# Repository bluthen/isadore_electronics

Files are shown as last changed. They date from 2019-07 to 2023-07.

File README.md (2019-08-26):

# isadore_electonics

Design files for the electronics of the Isadore Dryer Management System. Also included is what is called the MID software which queries the electronics and reports it back to the [isadore_server](https://github.com/bluthen/isadore_server/)

# Electronics Manufacture

Electronics manufactures usually want gerbers, centroid file, and a bill of materials. The latest pre-generated versions of these files can usually be found in the out directory (Example: `sensor_unitv3/out/`).

* The centroid and gerbers are in the zip file.
* The bill of materials is in the excel spreadsheet file (xlsx)
* An optional pins.png file may exist to show the manufacturer the location of pin1 for ICs.

Optionally you can generate the gerbers and centroid yourself depending by opening it up in [Eagle](https://www.autodesk.com/products/eagle/overview).

# Electronics Firmware

After you have a sensor unit or sensor hub, you need to program their firmware. To do this you need a AVR ISP programmer. Then there are script to help you program them. `sensor_unitv3/code/make.py`, `sensor_hubv3/code/Makefile`, and `fuse_crystal_clock.sh`.

*Note* you need a 5 pin ISP programmer. Most sold are 10 pin, so an adapter is needed.

To program the units or hubs you need some software installed:

* `avrdude`
* `gcc-avr`
* `avr-libc`

## Sensor Unit
A sensor unit can be programmed in many ways depending on what sensor modules you are going to plug into it.

Here is the help usage for `make.py`

```
Usage: make.py [OPTIONS] ADDRESS
  -h, --help                      Show this screen
  -d, --debug                     Debug build
  -p, --program                   Program unit
  -c, --clean                     Clean
  -f, --fuse                      Set fuse
  --prev303                       Build for prev3.03 unit
  --with-th                       Build with temperature humidty
  --with-pressurev1=m,b           Build in v1 pressure module
  --with-pressurev4a=cal_adjust   Build in v4a pressure module
  --with-pressurev4b=cal_adjust   Build in v4b pressure module
  --with-pressurev5=m,b           Build in v5 pressure module
  --with-anemometer               Build in Anemometer module
  --with-thermo                   Build in thermocouple module
  --with-multit                   Build in Multipoint-temp module
  --with-tach                     Build in tachometer module
```

So for example you might do with a unit, with the programmed placed and the unit powered.
```
python2 make.py -f -c -p --with-pressurev4b=0 102
```

If successful It is now programmed to use the pressurev4 module that gives you pressure/temperature/rh, and responses when address `102` is queried.

## Sensor Hub

To program the hub you would run with the programmer in place and powered:
```
cd sensor_hubv3/code
./fuse_crystal_clock.sh && make program
```

# MID (Master Interface Device)

This is basically the combination of a small computer (raspberry pi) and the hub electronics board. The hub and raspberry pi communicate serially. The hub has voltage regulators to power the raspberry pi.

## HUB<-> pi wiring

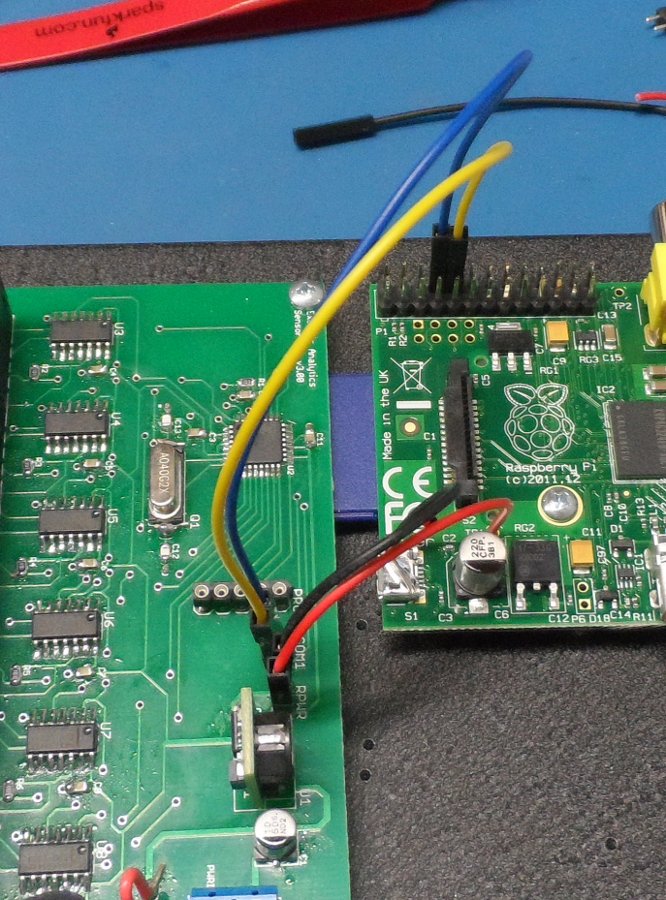
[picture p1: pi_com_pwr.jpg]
HUB Pi wiring diagram


Notice for the power, Red is on TP1, and black is outside of usb connector.

Communication headers on pins 4 and 5 from outside corner.

## Install and configure raspbian

After installing raspian you'll want to set to enable access to the serail port with `raspi-config` and [disable the use of console by uart](https://www.raspberrypi.org/documentation/configuration/uart.md).

```
$ raspi-config
Interface Options->Serial->No->Yes
```

You'll also want to make sure the following are installed:

```
apt-get install python python-pip python-dev
pip install flask pytz requests restkit pyserial pymodbus numpy termcolor netifaces netaddr
```

## Troubleshooting
There is a script called `midsim.py` that can aid in troubleshooting. It allows you to query sensors from the command line. It is located at `sensor_hubv3/code/test/midsim.py` 

Below is the usage:

```
Usage: midsim.py [OPTION]...
  -h, --help            show this screen
  -v, --verbose         output verbose debug output
  -c, --continous=t,c   Keep pulling every t seconds, c many times c=0 for infinite
                        default is to pull once.
  -f, --format=format   The output format to use:
                        default:   The default style output
                        csv:       csv style output
  -t, --type=TYPE       TYPE=(temphum|anemometer|tachometer|thermocouple|pressure|pressurewide|
                              multipointreset|multipointc[1-4]|multipointaddrc[1-4]|ping|
                              unitversion|hubversion) *Required
  --get-cal             Get calibration value for type
  --set-cal=CAL_VALUE   Set calibration value for type
  -p, --port=PORT       PORT=#
  -a, --address=ADDRESS ADDRESS=#,#,#,...
  -u                    use udp instead of serial
  -d, --device=PATH     serial device to use for version 3, default /dev/ttyAMA0
  -o                    Use direct command code instead of general (aka version2)
  -j                    Just send commands then exit immediatly
  -s, --server=IP:PORT  Start midsim server listening on IP:PORT
  -r, --remote=IP:PORT  Query remote midsim server on IP:PORT

  address,port required except for --type=ping
  Max number of addresses is 32.
```

## Calibration
The main goal of the pressure modules was to report differencial pressure. The pressure module can be calibrated and there is a script to help with that process. It takes a large amounts of samples and sets an offset to match the reference. This script can be found at `sensor_hubv3/code/test/calibrator.py`

## Configure mid_software

Copy the mid_software to the raspberry pi. Copy `MID.cfg.example` to `MID.cfg` but one directory down from the location of mid_software. Modify MID.cfg for your needs. The most importanted are `baseurl` and `MIDpassword`Below is a reference for what each key means:

* `baseurl` The url to the base location of your running instance of [isadore_server](https://github.com/bluthen/isadore_server/).
* `MIDname` If you have multiple mids, this needs to be set so it knows which config to fetch. If it doesn't exist, all configs are fetched.
* `MIDpassword` The mid password that was set for your instance of isadore_server.
* `configpath` relative url where it should get the systems unit configuration. shouldn't need changing.
* `uploadpath` the relative url it should use to upload sensor data it gets. shouldn't need changing.
* `rcstatuspath` the relative url it uses for controls. shouldn't need changing.
* `hub_serial` the serial port to use to communicate with the hub electronics board. `/dev/ttyAMA0` on old raspberry pi's, `/dev/serial0` on new ones.
* `STORE_RAW_DATA_MODE` shouldn't need changing
* `RAW_DATA_LOC` shouldn't need changing
* `RS485_TIMEOUT` time out per unit. shouldn't need changing
* `RS485_BAUD` The serial baud rate to use. shouldn't need changing
* `enableRC_p` shouldn't need changing
* `mid_reading_interval_seconds` The minimal amount of time to pass before reading sensor data again.
* `log_level` The level to log at, can be `ERROR`, `WARNING`, or `DEBUG`
* `turn_off` If it should be not be activly getting readings and uploading them.

There are also some other configurations for specific temperature controls. For now for those parameters, please see the code to find them.

## Running mid_software

Put the following in the crontab of the user that is going to run mid_software on the MID. Replace the path to where you copied mid_software.

```
*/15 * * * * /home/pi/mid_software/processCheck.sh
*/10 * * * * /home/pi/mid_software/mid_log_check.sh
```

* `processCheck.sh` will start the process if it doesn't find it running.
* `mid_log_check.sh` tries to detect if the process locked up and will restart it, if it thinks it has.

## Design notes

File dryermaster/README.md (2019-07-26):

# About dryermaster
This code is some example code to read from a dryer master output using SPI ADC Raspberry Pi hat.

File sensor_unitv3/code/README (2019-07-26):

Compile sensor unit with address and feature set

Addresses:
UNITADDR= # < 2^16

UNITFEATURES bit fields 1=enabled 0=disabled
1 bit -- temp-hum
2 bit -- anemometer
3 bit -- tachometer (not enabled, see tachometer code).
4 bit -- bearing/winding thermocouple (not enabled, see tachometer code).
5 bit -- Infineon KP pressure sensor
6 bit -- Freescale MPX pressure sensor

Note: If both KP and MPX are enabled, only KP is used.

UNITFEATURES=1   -- Just temp-hum
UNITFEATURES=2   -- Just anemometer
UNITFEATURES=3   -- both temp-hum and anemometer
UNITFEATURES=17  -- both temp-hum and KP pressure sensor
UNITFEATURES=33  -- both temp-hum and MPX pressure sensor
UNITFEATURE=19   -- temp-hum and KP pressure and annemometer

Ex:
UNITDEFS="-DUNITADDR=102 -DUNITFEATURES=17" make (makeopts)

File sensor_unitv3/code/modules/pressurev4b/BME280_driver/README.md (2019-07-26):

https://github.com/BoschSensortec/BME280_driver.git
CONTENTS OF THIS FILE
=======================
	* Introduction
	* Version
	* Integration details
	* Driver files information
	* Supported sensor interface
	* Copyright

INTRODUCTION
===============
	- This package contains the Bosch Sensortec MEMS humidity sensor driver(sensor API)
	- The sensor driver package includes bme280.h, bme280.c and bme280_support.c files
	
VERSION
=========
	- Version of bme280 sensor driver is:
		* bme280.c - V2.0.4
		* bme280.h - V2.0.4
		* bme280_support.c - V1.0.5

INTEGRATION DETAILS
=====================
	- Integrate bme280.h and bme280.c file in to your project.
	- The bme280_support.c file contains only examples for API use cases, so it is not required to integrate into project.

DRIVER FILES INFORMATION
===========================
	bme280.h
	-----------
		* This header file has the register address definition, constant definitions, data type definition and supported sensor driver calls declarations.

	 bme280.c
	------------
		* This file contains the implementation for the sensor driver APIs.

	 bme280_support.c
	----------------------
		* This file shall be used as an user guidance, here you can find samples of
    			* Initialize the sensor with I2C/SPI communication
        				- Add your code to the SPI and/or I2C bus read and bus write functions.
            					- Return value can be chosen by yourself
           					- API just passes that value to your application code
        				- Add your code to the delay function
        				- Change I2C address accordingly in bme280.h
   			* Power mode configuration of the sensor
   			* Get and set functions usage
			* Reading the sensor read out data

SUPPORTED SENSOR INTERFACE
====================================
	- This humidity sensor driver supports SPI and I2C interfaces

COPYRIGHT
===========
	- Copyright (C) 2013 - 2015 Bosch Sensortec GmbH

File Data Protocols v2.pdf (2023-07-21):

# Data Protocols v2

1 Overview 1.1 Unit Addresses 2 MID ↔ Sensor Hub 2.1 Commands 2.2 Sensor Hub Reply 2.2.1 Readings Reply Data 2.2.1.1 Temp and humidity reply 2.2.1.2 Wind speed reply 2.2.1.3 Tachometer reply 2.2.1.4 K Thermocouple reply 2.2.1.5 Barometric Pressure reply 2.2.1.6 Barometric Pressure Wide reply 2.2.1.7 Differential Pressure Wide reply 2.2.1.8 Multipoint Temp Sensor 2.2.1.8.1 Temperature Reading 2.2.1.8.2 Address Reading 2.2.1.9 Unit Version reply 2.2.1.10 Get Calibration Value reply 2.2.2 Successfully Executed Command (Reply Code 2) 2.2.3 Error Codes 3 Sensor Hub ↔ Sensor Unit 3.1 Changing Address 3.2 Calibration 3.2.1 Get Calibration 3.2.2 Set Calibration

MID ↔ WWW
JSON config download format (MID ← WWW) JSON reading data upload format (MID → WWW) Error codes

# 1 Overview

This document describes the data protocol for communication between EA custom hardware in the Isadore dryer monitoring system.

## 1.1 Unit Addresses

Each sensor unit has a 16 bit address stored in the programming ROM. The unit’s addresses are 16 bit for two reasons:

1. With new RS485 chips it is possible to have 256 or more units on one port. It also makes it easier to have a installation of units of all different addresses and there wouldn’t be a need to make sure they didn’t put one with the same address on the same port.
2. It would make it easier to use replacement units with less of a probability of same address. It is a similar reason why ethernet MAC addresses are 48 bit, no one has 2**48 network cards on a single switch.

# 2 MID ↔ Sensor Hub

The communication between Master Interface Device and Sensor hub will be done through a UDP/IP connection on Port 1082. The Master Interface Device will then send a magic code, command, and optional data (in a single packet), the Sensor Hub will reply to the MID by sending a single UDP packet to the port and address the original command came from. All data is in binary and little endian.

From Master Interface Device:
Magic (4B) | Command (1B) | Data ...
Reply from Sensor Hub:
Reply code(1B) Data...

The magic is 4 bytes:
Magic in hex | 0x44 0x45 0x52 0x56
Magic as little endian 4 byte int | 1448232260
Magic as ASCII | DERV

## 2.1 Commands

The commands the master interface device can send to the sensor hub are listed below. The command is a one byte number and is followed by data depending on the command. Note: the port numbers are one-based, not zero-based.

Command | Code | Data | Version notes
Get temp&hum reading(*) | 1 | Port,N,addr1,addr2,...,addrN ● Port is 1 x uint8 ● N is 1 x uint8 and is a value indicating how many addresses will be given. N needs to be less than or equal to 32 and greater than 0. If there are more than 32 devices connected you need to get the readings by querying again afterwards with another set of <=32 addresses. ● addrX is 1 x uint16 and corresponds to a Sensor Unit connected to the port on the Sensor Hub.
Get wind speed reading | 2 | Same as code 1
Get Tachometer | 3 | Same as code 1
Drive Hz & Current | 4 | Fill This
SP&PV and thermostat | 5 | Fill this
K thermocouple reading | 6 | Same as code 1
Barometric Pressure | 7 | Same as code 1
Barometric Pressure wide | 8 | Same as code 1 | Unit>=3.00
Differential Pressure wide | 14 | Same as code 1 | Unit>=3.01
Multipoint Temp sensor reset | 9 | Same as code 1 | Unit>=3.00
Multipoint Temp sensor reading channel 1 | 10 | Same as code 1 | Unit>=3.00

Multipoint Temp sensor reading channel 2 | 11 | Same as code 1 | Unit>=3.00
Multipoint Temp sensor reading channel 3 | 12 | Same as code 1 | Unit>=3.00
Multipoint Temp sensor reading channel 4 | 13 | Same as code 1 | Unit>=3.00
Multipoint Temp address reading chanel 1 | 14 | Same as code 1 | Unit>= 3.02
Multipoint Temp address reading chanel 2 | 15 | Same as code 1
Multipoint Temp address reading chanel 3 | 16 | Same as code 1
Multipoint Temp address reading chanel 4 | 17 | Same as code 1
General Unit Reading | 25 | Code,R,Port,N,addr1,addr2,...,addrN ● Code is 1 x uint8 from this table ● Port is 1 x uint8 ● R is 1 x uint8 length in bytes of the reply per address (max 8) ● N is 1 x uint8 number of addresses N <= 32 ● addrX is 1 x uint16 sensor unit address Note: Code becomes new command code. | Unit>=v3.00 Hub >=v3.00
Unit version | 63 | Same as code 1 | Unit>=v3.01
Calibration Value | 64 | Code,R,Port,N,addr1,addr2,...,addrN ● Code is 1 x uint8 from this table ● Port is 1 x uint8 ● R is 1 x uint8 length in bytes of the reply per address (max 8) ● N is 1 x uint8 number of | Hub>=3.03

| | addresses N <= 32 ● addrX is 1 x uint16 sensor unit address
Set Calibration Value | 65 | Code,D,Port,A,V ● Code is 1 x uint8 from this table of what calibration value to set. ● D is 1 x uint8 length in bytes of the calibration value V (max 8) ● Port is 1 x uint8 ● A is 1 x uint16 sensor unit address ● V is 1 x D bytes | Hub>=3.03
Ping | 130 | 1 x uint16
Hub version | 150 | 1 x uint16 | Hub>=3.03
Reserved | 200 | Reserved for unit change address (Section 3.1)

* - Time between measurements should be greater than 1s on per sensor basis to reduce the temperature sensor from heating up and reporting the heat of the chip instead of the air.
** - may not be implemented in prototype

## 2.2 Sensor Hub Reply

The sensor hub will give a reply after a command has been given. The reply may be any number of the following depending on the command. For example, a port reading command may have a reply of several error codes (Code 4) before a reading reply (Code 1). When the sensor is done replying it will disconnect the TCP/IP connection.

Reading time
The maximum time it takes for a unit to get temperature and humidity is 824ms although almost always it will be much faster. The base Hub will wait a maximum of N*4s. While the hub board is waiting it won't be able to process any other commands so the timeout should be greater than 128 seconds (32*4s) for the MID if the timeout needs to be set to a static value, or N*4s if it can be set dynamically. N is the number of units addressed.
Reply | Code | Data
Readings Reply | 1 | S,CC,DATA ● S 1xuint8, size in bytes of DATA ● CC 1 x uint8, original command code given

| | ● DATA is S bytes, see Readings Reply section below.
Success executed command | 2 | N,echo ● N is 1 x uint8 ● echo is data given in command. N is number of bytes in echo
Pong, response to Ping | 3 | P ● P is 1x uint16 and is the number given by Ping incremented by 1.
Error | 4 | L,C_1,A_2,..,C_L,A_L ● L is 1 x uint8 ● C_X is 1 x uint8 ● A_X is 1 x uint8 L<=N See Error Codes section for more details.
Hub version reply | 5 | V ● V is 1xuint16

### 2.2.1 Readings Reply Data

Type | CC | DATA
Temp and humidity reply | 1 | N,T1,H1,T2,H2,...,TN,HN ● N is 1 x uint8 ● TX is 1xuint16 ● HX is 1 x uint16 N should match N in initial command. See Temp and humidity reply section for more details.
Wind speed reply | 2 | N,V1,V2,...VN ● VX is 1 x uint16 See wind speed reply section for more details.

Tachometer reply | 3 | N,R1,R2,...,RN ● RX is 1 x uint16 See Tachometer reply section for more details.
Drive Hz & Current reply | 4 | V,I Fill out
SP&PV and Thermostat set value reply | 5 | Fill out
K thermocouple reply | 6 | N,W1,B1,W2,B2,...,WN,BN ● N is 1 x uint8 ● WX is 1 x uint16 TC 1 temp ● BX is 1 x uint16 TC 2 temp See K Thermocouple reply section for more details.
Barometric Pressure reply | 7 | N,P1,P2,...,PN ● N is 1 x uint8 ● PX is 1 x uint16 See Barometric Pressure reply section for more details.
Barometric Pressure wide reply | 8 | N,P1,P2,...,PN ● N is 1 x uint8 ● PX is 1 x uint32 See Barometric Pressure wide reply section for more details.
Differential Pressure wide reply | 14 | N,P1,P2,...,PN ● N is 1 x uint8 ● PX is 1 x uint32 See Differential Pressure wide reply section for more details.
Multipoint Temp Sensor reset reply | 9 | N,P1,P2,...,PN ● N is 1 x uint8 ● PX is 1 x uint8 See Multipoint Temp Sensor section below.
Multipoint Temp sensor reading address channel 1-4 reply | 14-17 | N,A1,A2,...,AN ● N is 1 x uint8 ● AX is 1 x uint64 See Multipoint Temp Sensor section below.
Multipoint Temp sensor reading temperature channel 1-4 reply | 10-13 | N,P1,P2,...,PN ● N is 1 x uint8 ● PX is 1 x uint16

| | See Multipoint Temp Sensor section below.
Unit version | 63 | N,V1,V2,...,VN ● VX is 1 x uint16 See Unit Version reply section for more details
Calibration value | 64 | N,V1,V2,...,VN ● VX is 1 x R See Calibration value reply section for more details
Reserved | 200 | Reserved (Section 3.1)

### 2.2.1.1 Temp and humidity reply

The temperature and humidity readings that are sent back are raw values replied back in the same order given in the command. Some calculations will have to be done.

Temperature Calculation
Note: This conversion works for both SHT-75 and PressureV4.1 sensors.
Temperature data is given to the MIB as uint16 (T), to convert this number into Fahrenheit :

1

F = d

1 + d
2

T

d

1 =− 40. 2

d

2 = 0. 018

Humidity Calculation
There are two sensor that give humidity the SHT-75 and PressureV4.1 module. An attempt was made to make the pressure module compatible was it proved difficult to keep the firmware size under 8k.

Humidity data is given to the MIB as uint16 (H),

PressureV4.1
RH

true = H/100. 0
Example H might be 3418
RH

true = 3418/100. 0 = 34. 19%

1See section 4.3 in SHT7X datasheet, sensor running at 5V.

SHT-75
The following conversions when SHT-75 is in use is listed below .

2

RHlinear = c

1 + c
2

H + c
3

H

2

c

1 =− 2. 0468

c

2 = 0. 0367

c

3 =− 1. 5955 · 10

−6

RH is relative humidity if temperature is 77F, to compensate for temperature you can use
linear
the formula below.

RH

true = T
| c

( − 25) t
1 + t
2
( | H) + RHlinear

t

1 = 0. 01

t

2 = 0. 00008

T

c = T
f

( − 32)/1. 8

T is temperature in Fahrenheit.
f

Unit unresponsive

If both temperature and humidity uint16 values are zero (0x0000) for a unit then that will indicate there was a problem getting the data for that addresses. An error reply code would also be given for that address.

Reference documents
- Introduction to Relative Humidity http://www.sensirion.com/en/pdf/product_information/Introduction_to_Relative_Humidity_E.pdf (http://www.sensirion.com/en/pdf/product_information/Introduction_to_Relative_Humidity_E.pdf)
- Humidity Formulae
http://www.sensirion.com/en/pdf/product_information/AN-humidity-formulae.pdf
- SHT7X datasheet
http://www.sensirion.com/en/pdf/product_information/Datasheet-humidity-sensor-SHT7x. pdf (http://www.sensirion.com/en/pdf/product_information/Datasheet-humidity-sensor-SHT7x.pdf)

### 2.2.1.2 Wind speed reply

V is the value from the unit, a rolling average of up to 30 30s time periods

2See section 4.1 and 4.2 in SHT7X datasheet.

To find V in mph:
V

mpℎ = V/100. 0

### 2.2.1.3 Tachometer reply

The replied value R is the last value of rpm calculated by the sensor. The following formula may be useful.

Calculate frequency (Hertz)
f = R/60

### 2.2.1.4 K Thermocouple reply

The following formula should be used to get the temperature in Celsius.

D is the integer value read.

T

c = 1023. 75

D
2

12

### 2.2.1.5 Barometric Pressure reply

The following formula should be used to get the absolute pressure in kilo pascals. D is the integer uint16 read.

P = 0. 0022888 · D + 50

It doesn’t matter which sensor is in the unit the MPX or KP the conversion to a common function is done in the unit.

### 2.2.1.6 Barometric Pressure Wide reply

The following formula should be used to get the absolute pressure in kilo pascals. D is the integer uint32 read. D comes in units of in Pascals.

P = D/1000. 0

Calibration info

- R - 4 (int32)
- V - value in pascals, positive or negative TODO: Not implemented

### 2.2.1.7 Differential Pressure Wide reply

The following formula should be used to get the differential pressure in kilopascals.
D is the integer uint32 read. D comes in units of centipascals. Note: This can report a negative pressure differential.

P = (D − 2147483647)/100000

Calibration info

- R - 4 (int32)
- V - value in centipascals, positive or negative TODO: Not implemented

### 2.2.1.8 Multipoint Temp Sensor

The multipoint temperature sensor module can takes cables with many temperature sensors on them.

### 2.2.1.8.1 Temperature Reading

Reading temperature values should go like the following:
1. X is the channel we want to read (1,2,3,4)
2. Multipoint Temp Reset (code 9) sent to units
3. Multipoint Temp reading (code [9+X]) sent to units
4. Repeat step 3. until all units report back 0xFFFF
5. If desire to read from another channel change start at step 1.
It is incorrect to change channels without a reset, it will give unexpected results.

On a multipoint temperature cable there are a number of ds18b20 sensors. When the unit gets the code to read the temperature it probes for a ds18b20 address, then reads the temperature from that address. When the unit gets the code again it will probe for the next ds18b20 address and read the temperature. At the point when there are no more ds18b20 temperature sensors on the cable it will reply back the value 0xFFFF. It will continue to reply 0xFFFF until a reset command is issued.

The order in which a value is read from a particular sensor is dependent on the sensor’s address and not the position the sensor is on the cable. The order will be the same for a particular cable. Thus sensors can be identified by query index, and one can manually map a location and query index.

The multipoint temperature sensor module supports up to four channels (Up to four multipoint sensor cables). You should never take readings from a different channel without sending a reset

first.

The number of sensors on a cable is not fixed, so you can have some units or channels with more or less sensors than others. This is why you should do readings until all sensors reply back 0xFFFF, while ignoring the units that reply with a 0xFFFF reading (This means you have reached the end of the sensors on that particular channel for that unit).

The following algorithm should be used to get the temperature in Celsius.
‘ds18b20_value’ sent to the function is the integer uint16 read.

double ds18b20_conversion(uint16_t ds18b20_value)
{
uint8_t digits;
uint8_t decimals;
uint16_t t = ds18b20_value; double negative = 1.0;
if (t & 0xF800) {
negative = -1.0;
t=~t+1;
}
digits = (uint8_t)((t&0x07F0) >> 4);
decimals = t & 0x000F;
return negative*((double)digits + (double)decimals/16.0);
}

If you want to test your conversion function, you can test with these values listed:

Value(Hex) | Temperature (C)
0x07D0 | 125
0x0550 | 85
0x0191 | 25.0625
0x00A2 | 10.125
0x0008 | 0.5
0x0000 | 0
0xFFF8 | -0.5
0xFF5E | -10.125

0xFE6F | -25.0625
0xFC90 | -55

### 2.2.1.8.2 Address Reading

Readings addresses is done in a similar fashion to reading the temperature. The size of the data returned is different(8 bytes instead of 2 bytes) and the command code is different.

Reading address values should go like the following:
1. X is the channel we want to read (1,2,3,4)
2. Multipoint Temp Reset (code 9) sent to units
3. Multipoint Temp reading (code [13+X]) sent to units
4. Repeat step 3. until all units report back 0xFFFFFFFF
5. If desire to read from another channel change start at step 1.
It is incorrect to change channels without a reset, it will give unexpected results.

### 2.2.1.9 Unit Version reply

V is integer uint16 read. V value to version

V Version

1 | 3.00 + V/100

Unit version before 3.01 do not support the version command code.

### 2.2.1.10 Get Calibration Value reply

See each code to see what the reply value means. Will get an error response back in calibration is currently not supported for a command code in the unit version.

### 2.2.2 Successfully Executed Command (Reply Code 2)

This reply command is only a valid reply for non-reading, and non-ping commands. For example this is a valid reply for command codes 5 and 6. You will not get this reply for command codes 1, 2, 3, 4, 7.

### 2.2.3 Error Codes

The error reply code data consists is composed of the following:

L(1B) | C_1(1B) | A_1(1B) | ... | C_L(1B) | A_L(1B)

The number of bytes in the data part of a error reply is 2*L+1. C_X is a code indicating the error listed in the below table. A_X is the index of the address of the sensor unit that had the error. If A_1=1 then the sensor unit from the first address given in command has the error C_1 associated with it. If A_X=0 this means it is a general error that doesn’t belong to any sensor unit.

Note: More error codes will probably get added later.

Code | Error | Includes Address | Recommended Action
1 | Ethernet board responsive but rest of sensor hub timed out. | No | Try request again.
2 | Invalid number of addresses to query on port reading. | No | Try request again.
3 | Reply size to large. This probably shouldn’t happen, it would indicate a bug somewhere in the microcontroller code. | No | Try request again.
4 | Sensor unit timed out or unit not on port. Address is the sensor unit that timed out. | Yes | Throw measurement away.
5 | Unsupported command code | No
6 | Sensor unit’s reply failed CRC8 check. | Yes | Throw measurement away.
7 | Unit reply size mismatch (wacked out unit, or wrong firmware or something). | Yes | Throw measurement away.
8 | Bad magic from MID. | No | Try request again.
9 | Hub timed out. (MID generated) | No | Try request again.
10 | Unit is not configured with sensor (Ex. Asked for wind speed when not configured with | Yes | Throw measurement away.

anemometer).

# 3 Sensor Hub ↔ Sensor Unit

The sensor hub will send a request addressed to a particular sensor unit on the correct port. The sensor unit and only that sensor unit will then respond through the RS485 network. Communication between sensor hub and sensor unit is binary little endian.

Request:
Magic (4B) | | Address (2B) | CC (1B)
Reply:
Magic (4B) | Address (2B) | CC(1B
| | )
S (1B) | Data
| | | (SB) CRC8 (1B)

## 3.1 Changing Address

This only works for v3 sensor units

Request:
Magic(4B) | 00 (2B) | 200 (1B) | New Address (2B)
Reply:
None

## 3.2 Calibration

### 3.2.1 Get Calibration

Request:
Magic (4B) | Address (2B) | 64(1B) | CC (1B)
Reply:
Magic (4B) | Address (2B) | 64(1B) | S (1B) | Data | CRC8

(SB) (1B)

### 3.2.2 Set Calibration

Request:
Magic (4B) | Address (2B) | 65(1B) | CC (1B) | V(DB)
Reply:
Magic (4B) | Address (2B) | 65(1B) | S (1B) | V (SB) | CRC8 (1B)

# MID ↔ WWW

## JSON config download format (MID ← WWW)

queryInterval:

midPass:

enabled_p:

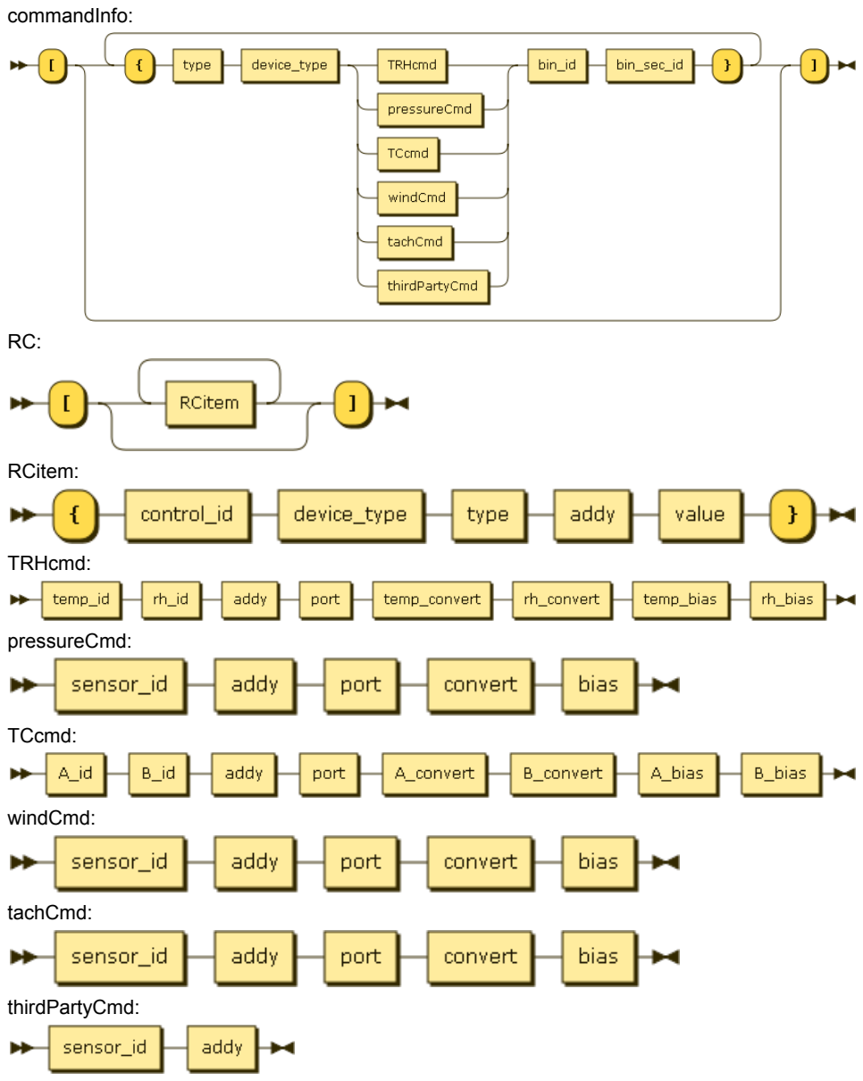
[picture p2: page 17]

commandInfo:

RC:

RCitem:

TRHcmd:

pressureCmd:

TCcmd:

windCmd:

tachCmd:

thirdPartyCmd:

Addy:

## JSON reading data upload format (MID → WWW)³

MIDtoWWW

passwd

datetime

data

errors

datum

### Error codes

Code | Description | Recommended action
1-10 | See table of MID/hub error codes
51 | Error encountered while parsing hub response | Throw measurement away

3Created using http://bottlecaps.de/rr/ui. EBNF syntax saved in MID repository.

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
hile
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
e, t

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
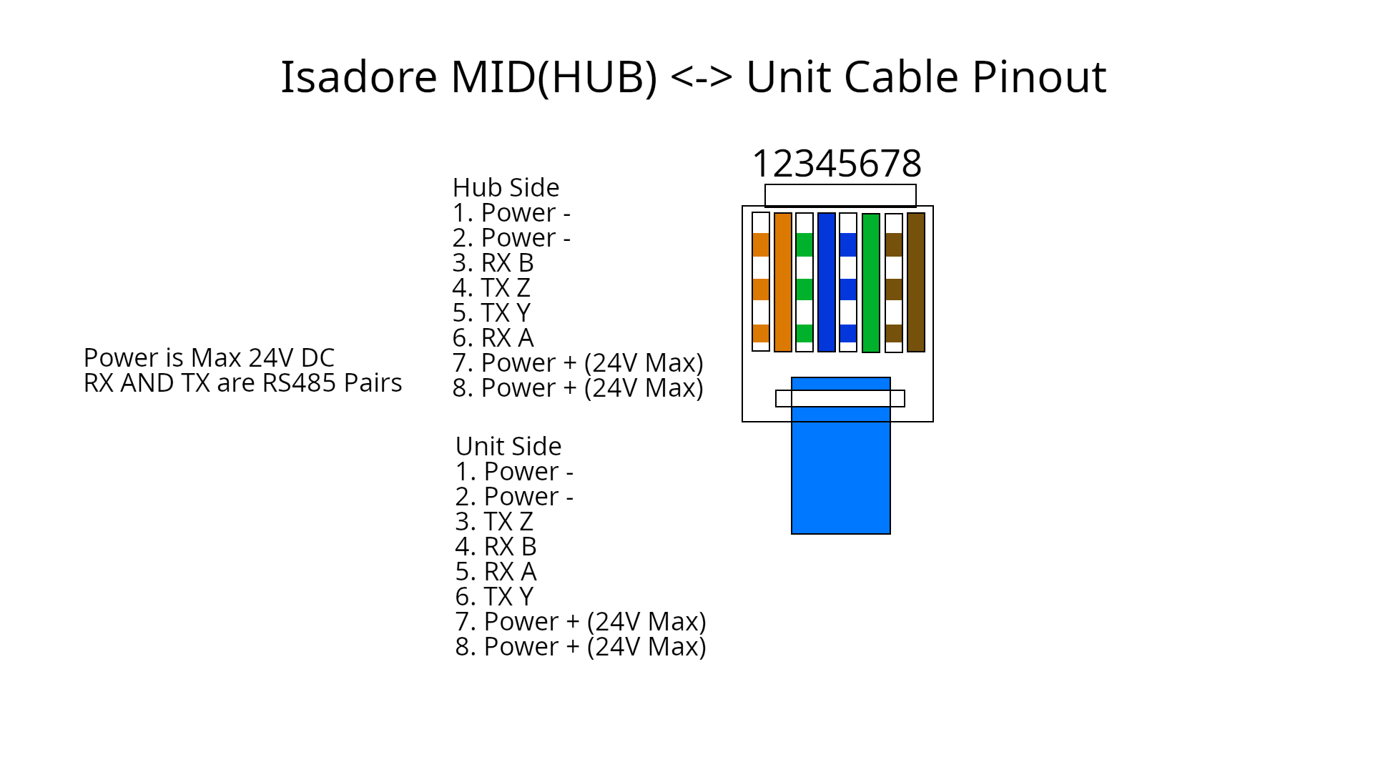
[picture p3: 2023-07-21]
HUB_UNIT_Pinout.png

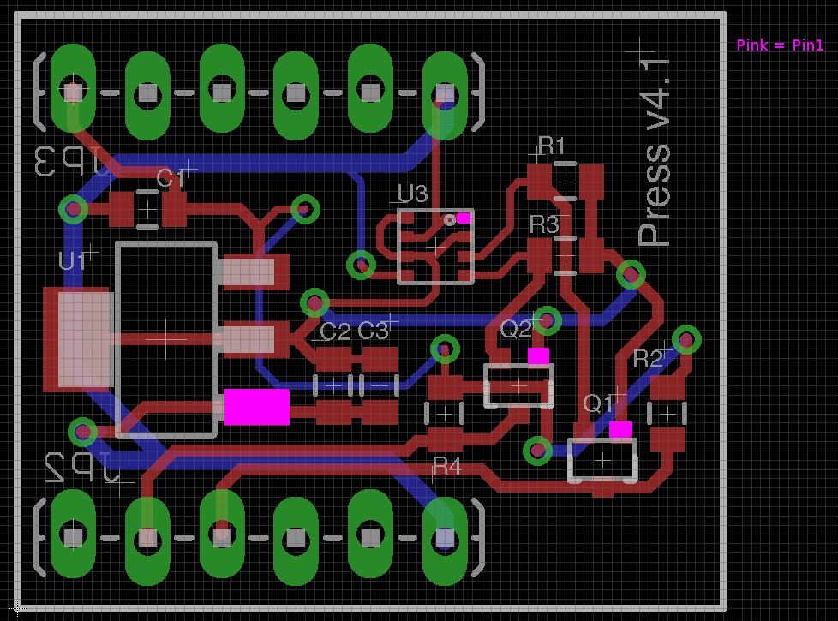
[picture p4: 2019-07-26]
sensor_unit_modules/pressureMv4/out/pressureMv4.10-pin1.png

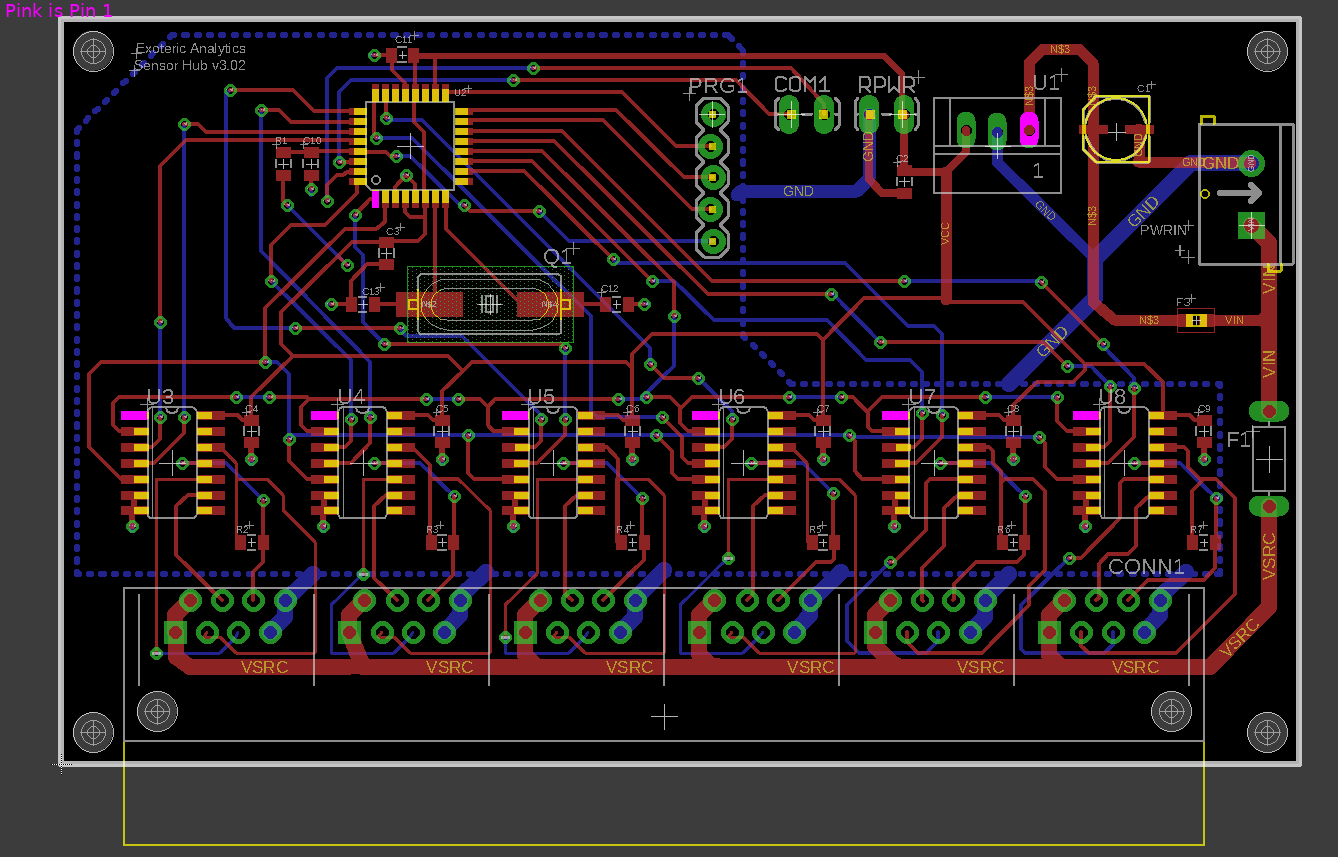
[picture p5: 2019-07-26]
sensor_hubv3/out/sensor_hubv3.02pins.png

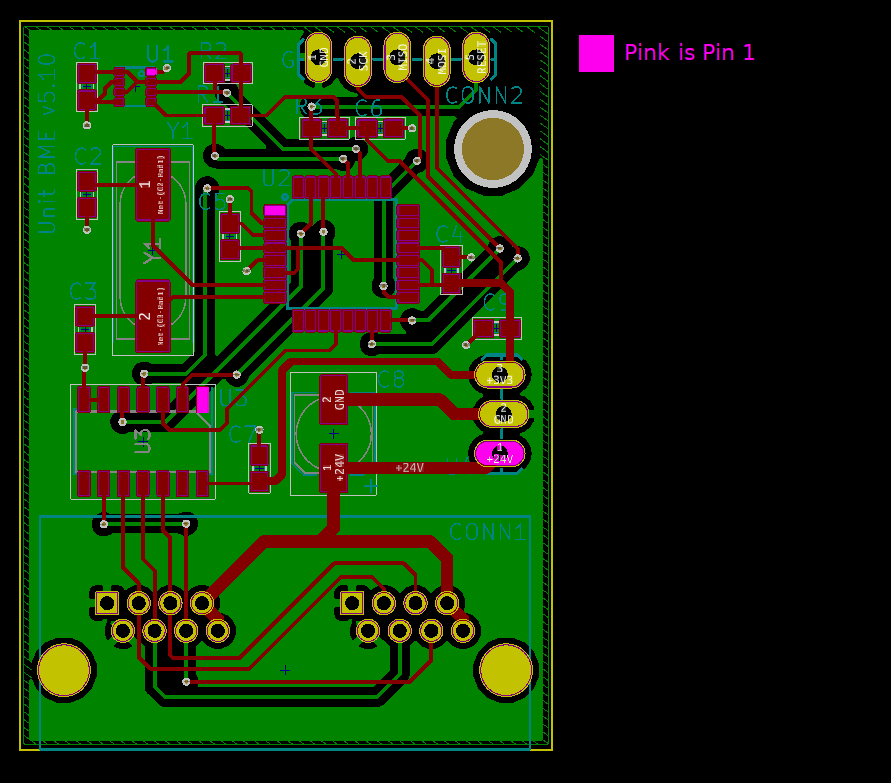
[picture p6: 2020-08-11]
sensor_unit_bme280/gerbers/sensor_unit_bme280v5.10_pin1.png

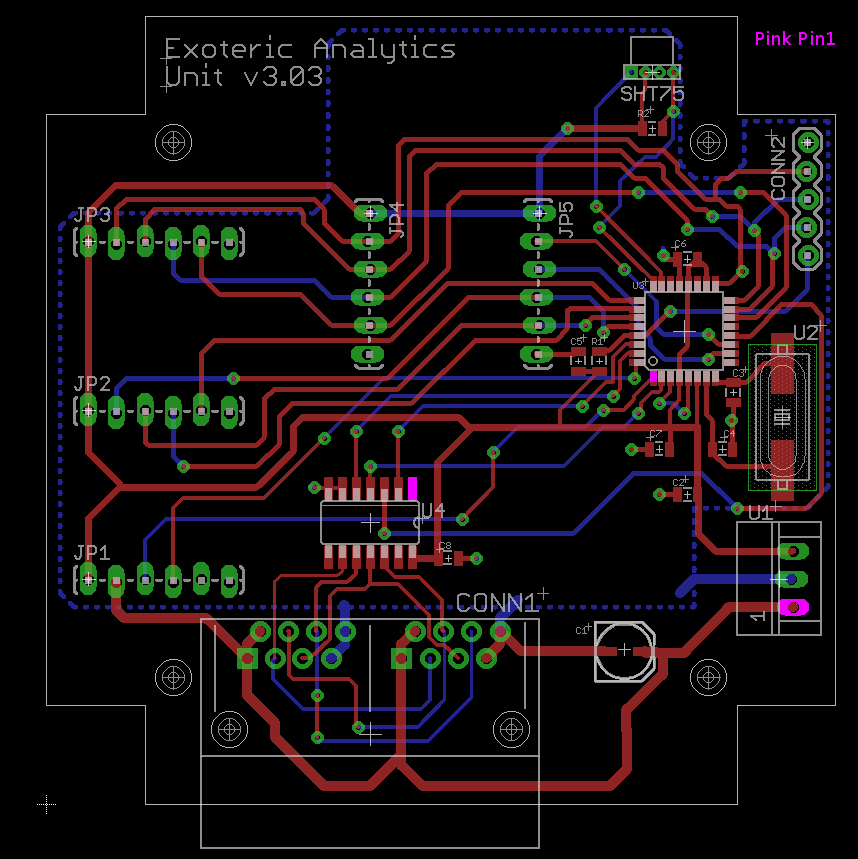
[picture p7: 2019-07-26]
sensor_unitv3/out/sensor_unitv3.03pins.png

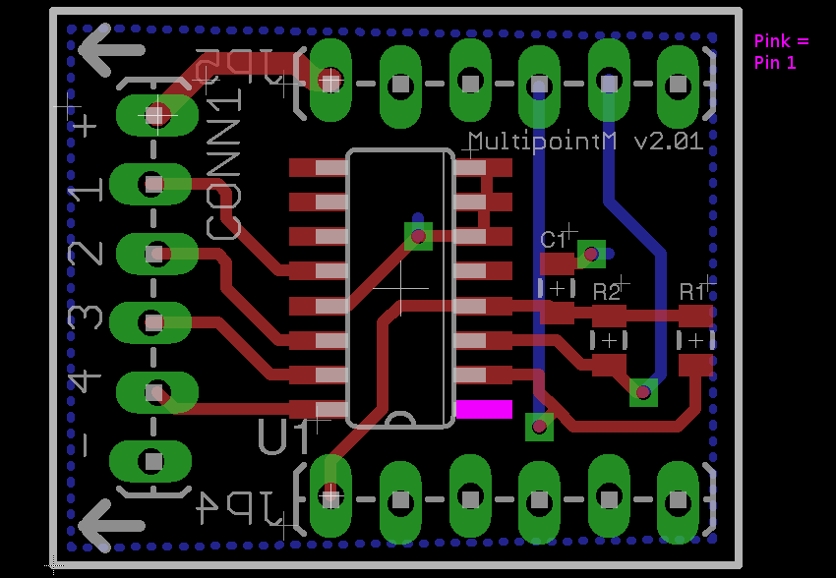
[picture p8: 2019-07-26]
sensor_unit_modules/multipointMv2/out/multipointMv2.01-pin1.png

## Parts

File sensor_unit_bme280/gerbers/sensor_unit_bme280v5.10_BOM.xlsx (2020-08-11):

Labels | Part | Primary Source | Notes
C1, C4, C5, C6, C7 | 0603 0.1uF/50V X7R | Digikey: 445-5666-1-ND (https://www.digikey.com/product-detail/en/tdk-corporation/CGA3E2X7R1H104K080AA/445-5666-1-ND/2443706)
C2, C3 | 0603 22pF 10V cap | Digikey: 399-7874-1-ND (https://www.digikey.com/product-detail/en/kemet/C0603C220J1GACTU/399-7874-1-ND/3471597)
C8 | Panasonic C 10UF 50V | Digikey: PCE4608CT-ND (https://www.digikey.com/product-detail/en/panasonic-electronic-components/EEE-1HA100WAR/PCE4608CT-ND/1718031)
C9 | 0603 10uF/10V | Digikey: 490-14372-1-ND (https://www.digikey.com/product-detail/en/murata-electronics/GRM188R61A106KE69J/490-14372-1-ND/6606833)
CONN1 | connector - 2 port Female RJ45 (8P8C) | Digikey: E5J88-00AJG2-L (https://www.digikey.com/product-detail/en/pulse-electronics-network/E5J88-00AJG2-L/1840-1049-ND/1785309)
CONN2 | Leave unpopulated | Leave unpopulated
R1, R2 | 0603 4.7k ohm resistor | Digikey: 311-4.7KGRCT-ND (https://www.digikey.com/product-detail/en/yageo/RC0603JR-074K7L/311-4.7KGRCT-ND/729732)
R3 | 0603 10k ohm resistor | Digikey: P10KGCT-ND (https://www.digikey.com/product-detail/en/panasonic-electronic-components/ERJ-3GEYJ103V/P10KGCT-ND/134717)
U1 | BME280 Sensor | Digikey: 828-1063-1-ND (https://www.digikey.com/product-detail/en/bosch-sensortec/BME280/828-1063-1-ND/6136314)
U2 | TQFP ATMega328 | Digikey: ATMEGA328P-AURCT-ND (http://www.digikey.com/product-detail/en/atmel/ATMEGA328P-AUR/ATMEGA328P-AURCT-ND/3789455)
U3 | 14-SOIC RS485 fullduplex transceiver 3.3V | Digikey: ISL83070EIBZA-TCT-ND (https://www.digikey.com/product-detail/en/renesas-electronics-america-inc/ISL83070EIBZA-T/ISL83070EIBZA-TCT-ND/1034268)
U4 | DC-DC 3.3V Switching regulator | Digikey: VXO7803-500 (https://www.digikey.com/product-detail/en/cui-inc/VXO7803-500/102-4248-ND/7350287)
Y1 | HC49 4 Mhz Crystal | Digikey: 535-10202-1-ND (http://www.digikey.com/product-detail/en/ABLS-4.000MHZ-B4-T/535-10202-1-ND/2184237)

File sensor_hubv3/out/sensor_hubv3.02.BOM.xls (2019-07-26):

Labels | Part | Digikey (Digikey #) | Newark (Newark #)
U1 | Power module OKI-78SR | 0
U2 | TQFP ATMega328 | 0
U3, U4, U5, U6, U7, U8 | SOIC-14 MAX13448 +/-80V Fault protection RS485 full duplex transceiver | 0
Q1 | HC49 4 Mhz Crystal | 0
C2 | 0805 10uF/10V | 0
C1 | Panasonic C 10UF 50V | 0
C3, C4, C5, C6, C7, C8, C9, C10, C11 | 0805 0.1 uF 10V cap | 0
C12, C13 | 0805 22pF 10V cap | 0
R1 | 0805 10k resistor | 0
R2, R3, R4, R5, R6, R7 | 0805 100 Ohm resistor | 0
PRG1 | female swiss header .1" 5 position straight | 0
CONN1 | 6 port Female RJ45 Connector | 0
COM1, RPWR | 0.1" male headers | 0
F1 | 25 Ohm 2A NTC |  | 0
F3 | 0603 0 ohm resistor (jumper) | 541-0.0GTR-ND
PWRIN | Screw Terminals 5mm Pitch (2-Pin) | 0

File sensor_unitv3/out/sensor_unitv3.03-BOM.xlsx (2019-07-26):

Labels | Part | Primary Source
C1 | Panasonic C 10UF 50V | Digikey: PCE4608CT-ND (https://www.digikey.com/product-detail/en/panasonic-electronic-components/EEE-1HA100WAR/PCE4608CT-ND/1718031)
C2 | 0805 10uF/10V | Digikey: 399-8015-2-ND (http://www.digikey.com/product-detail/en/kemet/C0805C106Z8VACTU/399-8015-2-ND/2211789)
C3, C4 | 0805 22pF 10V cap | Digikey: 399-1113-1-ND (http://www.digikey.com/product-detail/en/C0805C220J5GACTU/399-1113-1-ND/411388)
C5, C6, C7, C8 | 0805 0.1 uF 10V cap | Digikey: 478-3755-1-ND (http://www.digikey.com/product-detail/en/08053C104KAT2A/478-3755-1-ND/1116453)
CONN1 | connector - 2 port Female RJ45 (8P8C) | Digikey: A31449-ND (https://www.digikey.com/product-detail/en/te-connectivity-amp-connectors/5557560-1/A31449-ND/769593)
CONN2 | female swiss header .1" 5 position straight | Digikey: SAM1119-32-ND (http://www.digikey.com/product-detail/en/SS-132-TT-2/SAM1119-32-ND/1105687)
JP1, JP2, JP3, JP4, JP5 | female header .1" 6 position straight | Digikey: S7004-ND (http://www.digikey.com/product-detail/en/PPTC061LFBN-RC/S7004-ND/810145)
R1, R2 | 0805 10k resistor | Digikey: 311-10KARCT-ND (http://www.digikey.com/product-detail/en/RC0805JR-0710KL/311-10KARCT-ND/731188)
SHT75 | header .050" GRID 4 POS straight | Digikey: S9008E-04-ND (http://www.digikey.com/product-detail/en/LPPB041NFFN-RC/S9008E-04-ND/1786362)
U1 | Power module OKI-78SR | Digikey: 811-2196-5-ND (http://www.digikey.com/product-detail/en/OKI-78SR-5%2F1.5-W36-C/811-2196-5-ND/2259781)
U2 | HC49 4 Mhz Crystal | Digikey: 535-10202-1-ND (http://www.digikey.com/product-detail/en/ABLS-4.000MHZ-B4-T/535-10202-1-ND/2184237)
U3 | TQFP ATMega328 | Digikey: ATMEGA328P-AURCT-ND (http://www.digikey.com/product-detail/en/atmel/ATMEGA328P-AUR/ATMEGA328P-AURCT-ND/3789455)
U4 | SOIC-14 MAX13448 +/-80V Fault protection RS485 full duplex transceiver | Digikey: MAX13448EESD+-ND (http://www.digikey.com/product-detail/en/MAX13448EESD%2B/MAX13448EESD%2B-ND/1937474)

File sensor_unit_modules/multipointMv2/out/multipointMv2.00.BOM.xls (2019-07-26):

Labels | Part | Digikey (Digikey #) | Mouser (Mouser Part #)
U1 | SO16 DS2482S-800 1-wire bridge | DS2482S-800+-ND | 700-DS2482S-800
R1, R2 | 0805 4.7k Ohm resistor | 311-4.7KARCT-ND
C1 | 0805 0.1uF capacitor 10V | 478-3755-1-ND
JP4, JP5 | header 14.5mm 6 way long leds (arduino like) |  | 782-A000084
CONN1 | 0.1" 6 pos screw terminal block | A98337-ND

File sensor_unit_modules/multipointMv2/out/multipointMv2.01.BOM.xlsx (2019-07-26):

Labels | Part | Primary Source | Secondary Source | Notes
U1 | SO16 DS2482S-800 1-wire bridge | Digikey: DS2482S-800+-ND (http://www.digikey.com/product-detail/en/DS2482S-800%2B/DS2482S-800%2B-ND/1197437) | Mouser: 700-DS2482S-800 (http://www.mouser.com/ProductDetail/Maxim-Integrated/DS2482S-800+/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)
R1, R2 | 0805 4.7k Ohm resistor | Digikey: 311-4.7KARCT-ND (http://www.digikey.com/product-detail/en/RC0805JR-074K7L/311-4.7KARCT-ND/731274)
C1 | 0805 0.1uF capacitor 10V | Digikey: 478-3755-1-ND (http://www.digikey.com/product-detail/en/08053C104KAT2A/478-3755-1-ND/1116453)
JP4, JP5 | 0.1" male headers 6conn | Digikey: A26514-40-ND (http://www.digikey.com/product-detail/en/4-103327-0/A26514-40-ND/297924) |  | Mounted on the back
CONN1 | 0.1" 6 pos screw terminal block | Digikey: A98337-ND (http://www.digikey.com/product-detail/en/282834-6/A98337-ND/1153267)

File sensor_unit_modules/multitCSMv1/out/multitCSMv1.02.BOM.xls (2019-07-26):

Labels | Part | Primary Source | Secondary Source | Assembly Notes
U1 | 8-SOIC DS18B20 | DS18B20Z+-ND (http://www.digikey.com/product-detail/en/DS18B20Z%2B/DS18B20Z%2B-ND/956982) | 700-DS18B20Z (http://www.mouser.com/ProductDetail/Maxim-Integrated/DS18B20Z+/?qs=sGAEpiMZZMvbyeSUH4qH%2fLnY%252bzqr5uOI)
P1, P2 | 3 conn screw terminal, 0.150" (3.81mm) pitch | Digikey: 609-3919-ND (https://www.digikey.com/product-search/en?keywords=609-3919-ND) |  | Connection slots facing outward

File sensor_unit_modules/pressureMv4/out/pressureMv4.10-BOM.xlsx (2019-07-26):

Labels | Part | Primary Source | Secondary Source | Notes
U1 | SOT-223 LM1117 compatible LDO 3.3V Voltage Regulator | Digikey: NCP1117LPST33T3GOSCT-ND (http://www.digikey.com/product-detail/en/NCP1117LPST33T3G/NCP1117LPST33T3GOSCT-ND/3462387)
U2 | BME280 | Digikey: 828-1063-1-ND (https://www.digikey.com/product-detail/en/bosch-sensortec/BME280/828-1063-1-ND/6136314) | Future Electronics: BME280BOSCH2053946 (http://www.futureelectronics.com/en/Technologies/Product.aspx?ProductID=BME280BOSCH2053946&IM=0)
C1, C2 | 0805 10uF/10V X7R | Digikey: 399-8015-2-ND (http://www.digikey.com/product-detail/en/kemet/C0805C106Z8VACTU/399-8015-2-ND/2211789)
R1, R2, R3, R4 | 0805 10k Ohm resistor | Digikey: 311-10KARCT-ND (http://www.digikey.com/product-detail/en/RC0805JR-0710KL/311-10KARCT-ND/731188)
C3 | 0805 0.1uF capacitor 10V X7R | Digikey: 478-3755-1-ND (http://www.digikey.com/product-detail/en/08053C104KAT2A/478-3755-1-ND/1116453)
Q1, Q2 | BSS138 FET SOT-323 | Digikey: BSS138WCT-ND (http://www.digikey.com/product-detail/en/BSS138W/BSS138WCT-ND/3907886)
JP2, JP3 | 0.1" male headers 6conn | A26514-40-ND (http://www.digikey.com/product-detail/en/4-103327-0/A26514-40-ND/297924) |  | Mounted on the back

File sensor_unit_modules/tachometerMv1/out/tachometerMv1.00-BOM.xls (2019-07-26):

Labels | Part | Digikey (Digikey #) | Mouser (Mouser Part #)
42EF | terminal block - 3 pin, 0.1" spacing | A98334-ND
JP1, JP2 | header 14.5mm 6 way long leds (arduino like) |  | 782-A000084

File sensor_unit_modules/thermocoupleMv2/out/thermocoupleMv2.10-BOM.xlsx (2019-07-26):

Labels | Part | Primary Source | Secondary Source | Assembly/Substitute part Notes
TC | terminal block - 2 pin, 0.1" spacing | Digikey: A98334-ND (http://search.digikey.com/scripts/DkSearch/dksus.dll?lang=en&site=US&KeyWords=A98334-ND&x=32&y=19)
JP2, JP3 | 0.1" male headers 6conn | Digikey: A26514-40-ND (http://www.digikey.com/product-detail/en/4-103327-0/A26514-40-ND/297924) |  | Mounted on the back
U1 | SOT-223 LM1117 compatible LDO 3.3V Voltage Regulator | Digikey: NCP1117LPST33T3GOSCT-ND (http://www.digikey.com/product-detail/en/NCP1117LPST33T3G/NCP1117LPST33T3GOSCT-ND/3462387)
C1, C2, C3 | 0805 10uF/10V | Digikey: 445-1371-1-ND (http://www.digikey.com/product-detail/en/C2012Y5V1A106Z/445-1371-1-ND/567608)
C4 | 0805 0.1uF capacitor 10V | Digikey: 478-3755-1-ND (http://www.digikey.com/product-detail/en/08053C104KAT2A/478-3755-1-ND/1116453)
R1, R2, R3, R4 | 0805 10k resistor | Digikey: 311-10KARCT-ND (http://www.digikey.com/product-detail/en/RC0805JR-0710KL/311-10KARCT-ND/731188)
U2 | MAX31855KASA+ Type K | Digikey: MAX31855KASA+TCT-ND (http://www.digikey.com/product-detail/en/MAX31855KASA%2BT/MAX31855KASA%2BTCT-ND/2708805)

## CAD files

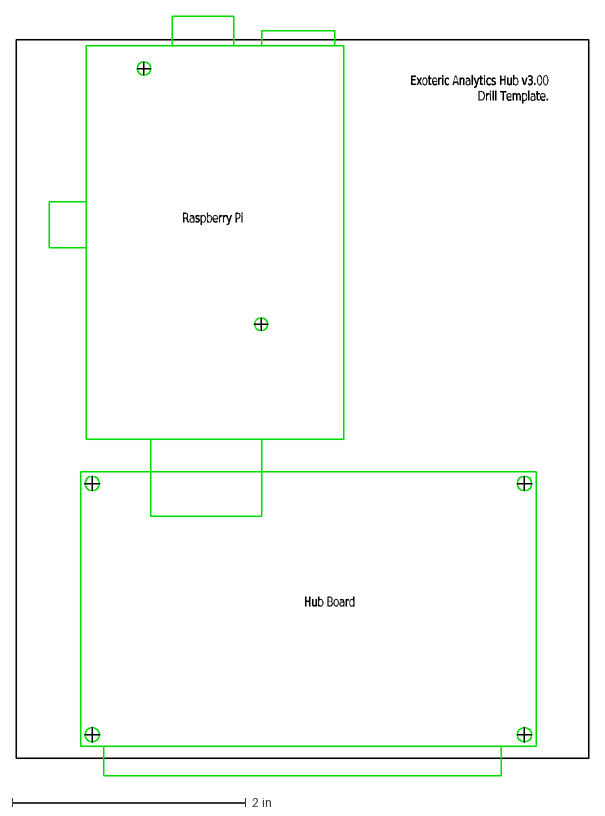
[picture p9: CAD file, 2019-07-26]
enclosures/hubv3/hub_drill_template_v3.00.dxf
Exoteric\~Analytics\~Hub\~v3.00\~ Drill\~Template.
Raspberry\~Pi
Hub\~Board

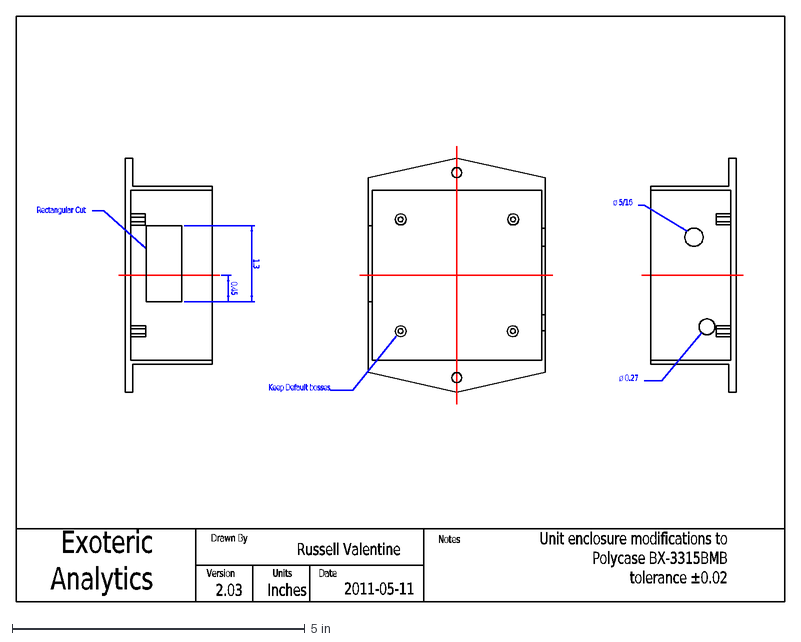
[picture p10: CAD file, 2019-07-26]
enclosures/unit_enclosure_v2.03.dxf
Exoteric \~\~Analytics
Drawn\~By
Notes
Date
Version
Russell\~Valentine
Units
Inches
Rectangular\~Cut
1.3
0.45
2.03
Keep\~Default\~bosses
ø\~0.27
Unit\~enclosure\~modifications\~to\~ Polycase\~BX-3315BMB\~ tolerance\~±0.02
ø\~5/16
2011-05-11

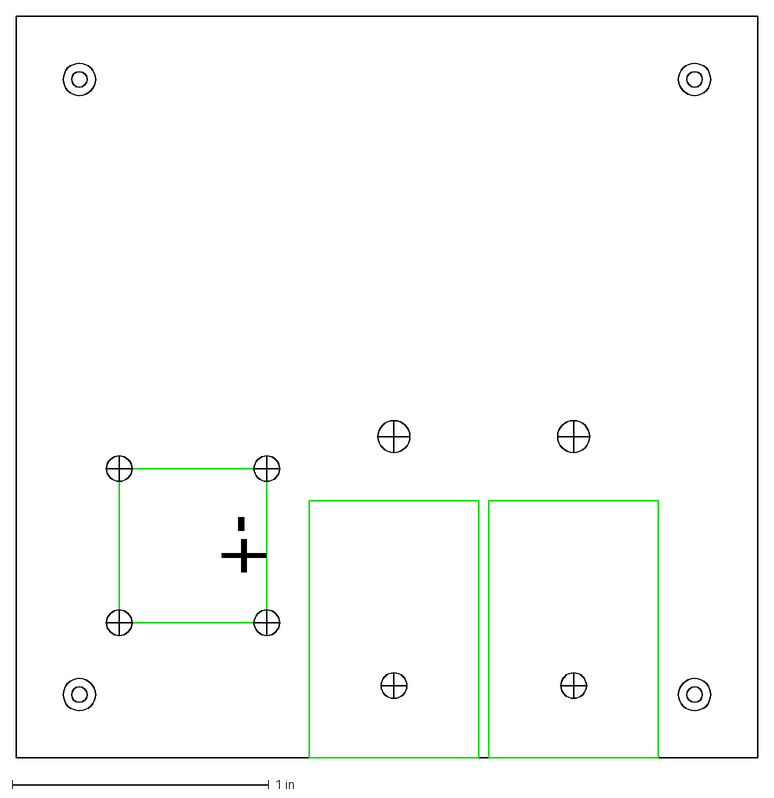
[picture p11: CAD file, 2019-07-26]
enclosures/thermo_drill_template.dxf
-+

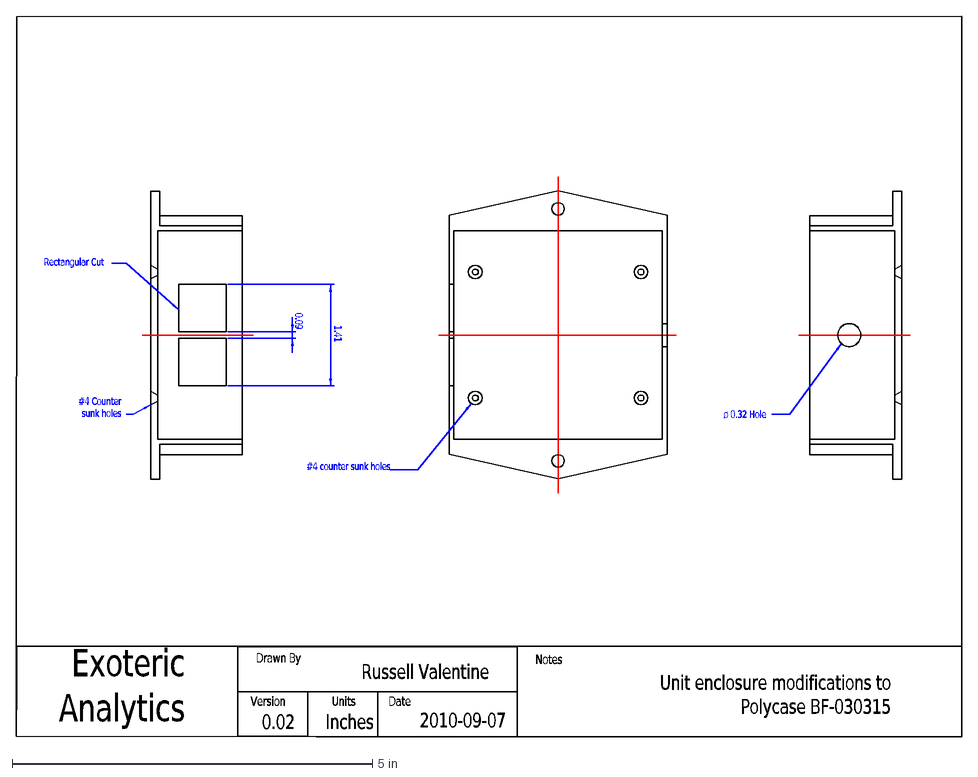
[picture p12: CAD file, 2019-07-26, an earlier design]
enclosures/unit_enclosure_v1.00.dxf
1.41
0.09
Rectangular\~Cut
ø\~0.32\~Hole
Exoteric \~\~Analytics
Drawn\~By
Notes
Date
Version
Russell\~Valentine
2010-09-07
Unit\~enclosure\~modifications\~to\~ Polycase\~BF-030315\~
Units
Inches
#4\~counter\~sunk\~holes
#4\~Counter\~ sunk\~holes
0.02

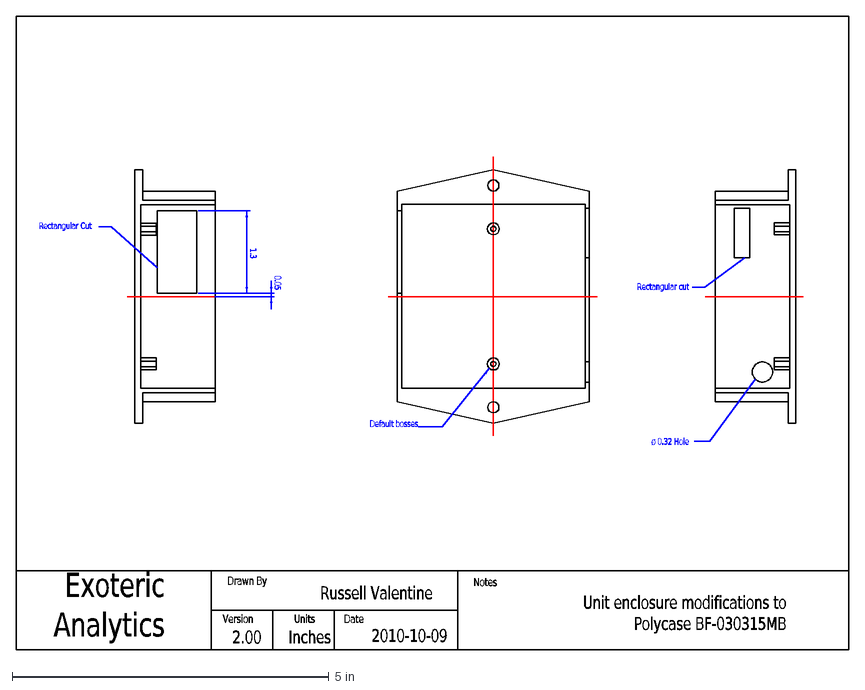
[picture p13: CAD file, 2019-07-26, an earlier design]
enclosures/unit_enclosure_v2.00.dxf
Exoteric \~\~Analytics
Drawn\~By
Notes
Date
Version
Russell\~Valentine
Units
Inches
Default\~bosses
Rectangular\~Cut
2.00
1.3
0.05
Rectangular\~cut
Unit\~enclosure\~modifications\~to\~ Polycase\~BF-030315MB\~
2010-10-09
ø\~0.32\~Hole

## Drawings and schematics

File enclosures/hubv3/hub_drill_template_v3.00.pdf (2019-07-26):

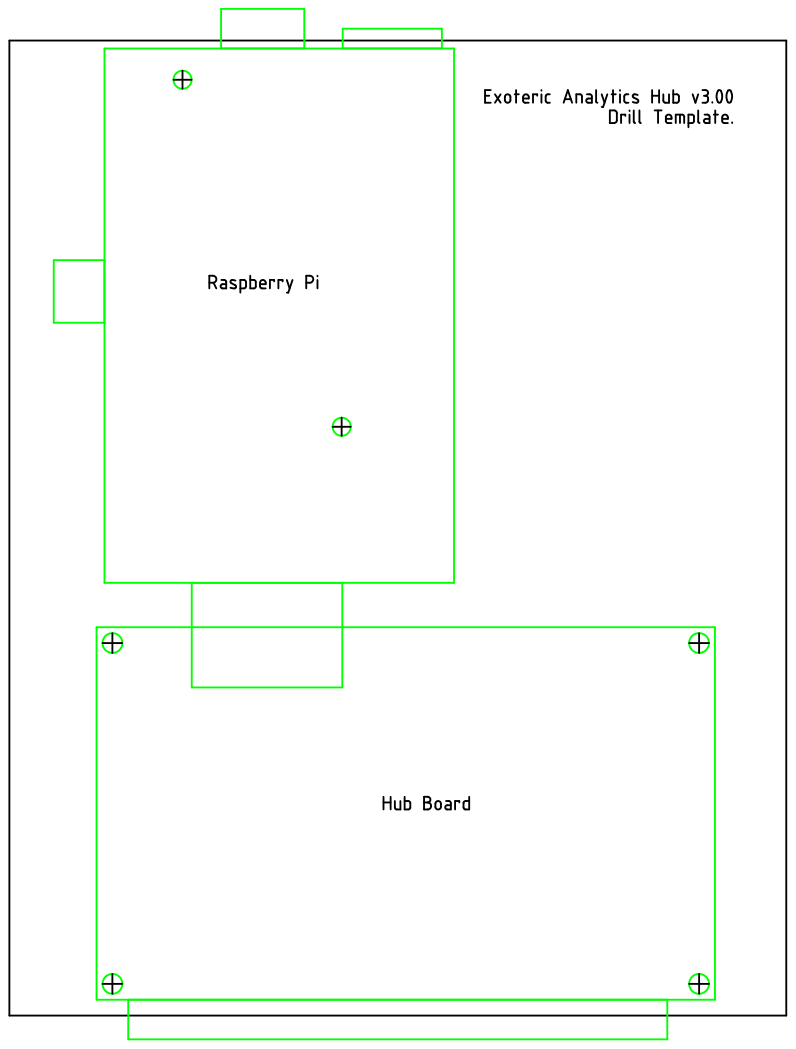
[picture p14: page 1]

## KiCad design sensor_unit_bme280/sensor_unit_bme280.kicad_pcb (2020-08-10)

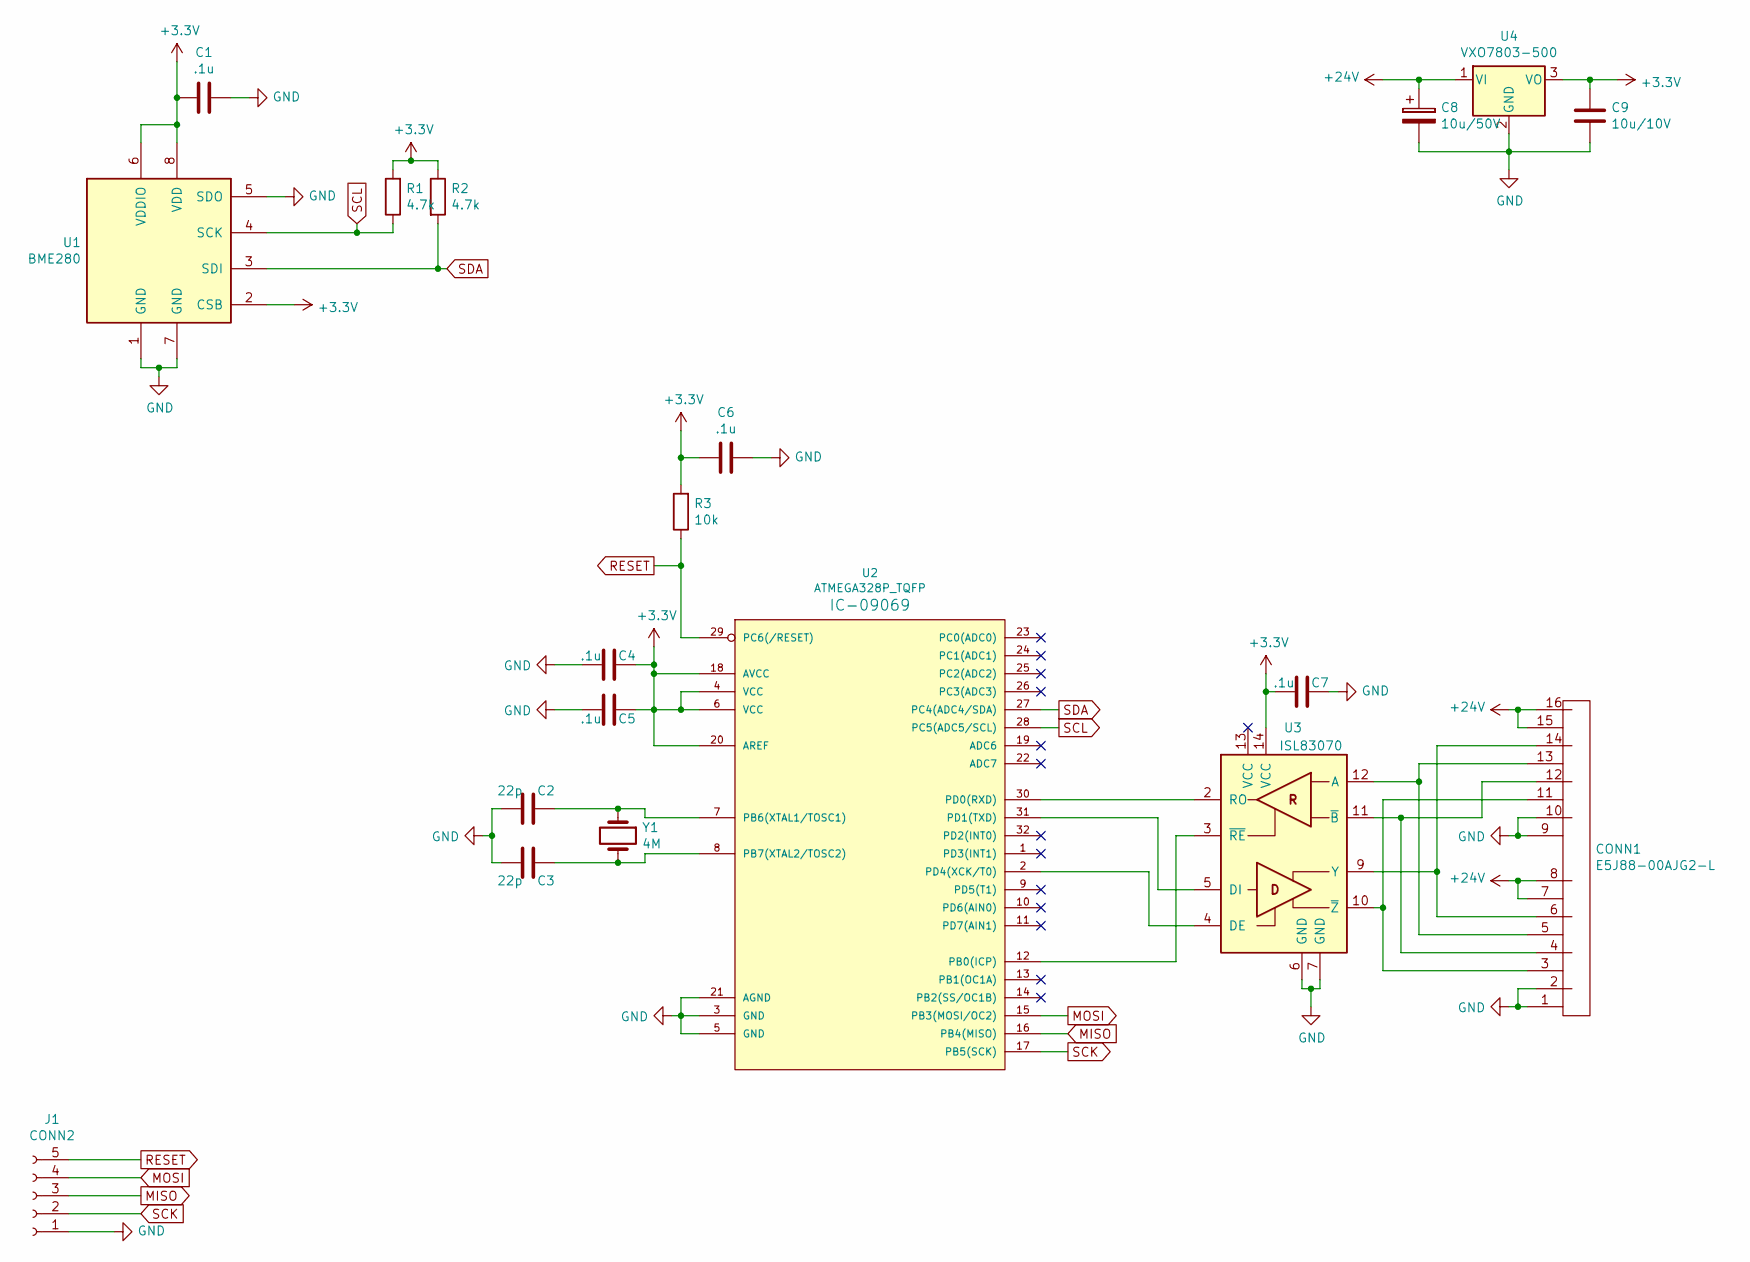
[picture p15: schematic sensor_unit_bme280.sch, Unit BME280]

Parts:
C1, C4, C5, C6, C7: .1u; 0603
C2, C3: 22p; 0603
C8: 10u/50V; CP_Elec_5x5.3
C9: 10u/10V; 0603
CONN1: E5J88-00AJG2-L
J1: CONN2; 1X05_LOCK_LONGPADS
R1, R2: 4.7k; 0603
R3: 10k; 0603
U1: BME280
U2: ATMEGA328P_TQFP; TQFP32-08
U3: ISL83070; SOIC-14_3.9x8.7mm_Pitch1.27mm
U4: VXO7803-500; 1X03_LOCK_LONGPADS
Y1: 4M; Crystal_SMD_HC49-SD

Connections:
+3V3: C1.2, C4.1, C5.1, C6.1, C7.2, C9.1, R1.2, R2.1, R3.2, U1.2 (CSB), U1.6 (VDDIO), U1.8 (VDD), U2.4 (VCC), U2.6 (VCC), U2.18 (AVCC), U2.20 (AREF), U3.14 (VCC), U4.3 (VO)
+24V: C8.1, CONN1.7, CONN1.8, CONN1.15, CONN1.16, U4.1 (VI)
GND: C1.1, C2.2, C3.2, C4.2, C5.2, C6.2, C7.1, C8.2, C9.2, CONN1.1, CONN1.2, CONN1.9, CONN1.10, J1.1, U1.1 (GND), U1.5 (SDO), U1.7 (GND), U2.3 (GND), U2.5 (GND), U2.21 (AGND), U3.6 (GND), U3.7 (GND), U4.2 (GND)
MISO: J1.3, U2.16 (PB4(MISO))
MOSI: J1.4, U2.15 (PB3(MOSI/OC2))
unnamed: C2.1, U2.7 (PB6(XTAL1/TOSC1)), Y1.1
unnamed: C3.1, U2.8 (PB7(XTAL2/TOSC2)), Y1.2
unnamed: CONN1.3, CONN1.11, U3.10 (~Z~)
unnamed: CONN1.4, CONN1.12, U3.11 (~B)
unnamed: CONN1.5, CONN1.13, U3.12 (A)
unnamed: CONN1.6, CONN1.14, U3.9 (Y)
unnamed: U2.2 (PD4(XCK/T0)), U3.4 (DE)
unnamed: U2.12 (PB0(ICP)), U3.3 (~RE)
unnamed: U2.30 (PD0(RXD)), U3.2 (RO)
unnamed: U2.31 (PD1(TXD)), U3.5 (DI)
RESET: J1.5, R3.1, U2.29 (PC6(/RESET))
SCK: J1.2, U2.17 (PB5(SCK))
SCL: R1.1, U1.4 (SCK), U2.28 (PC5(ADC5/SCL))
SDA: R2.2, U1.3 (SDI), U2.27 (PC4(ADC4/SDA))

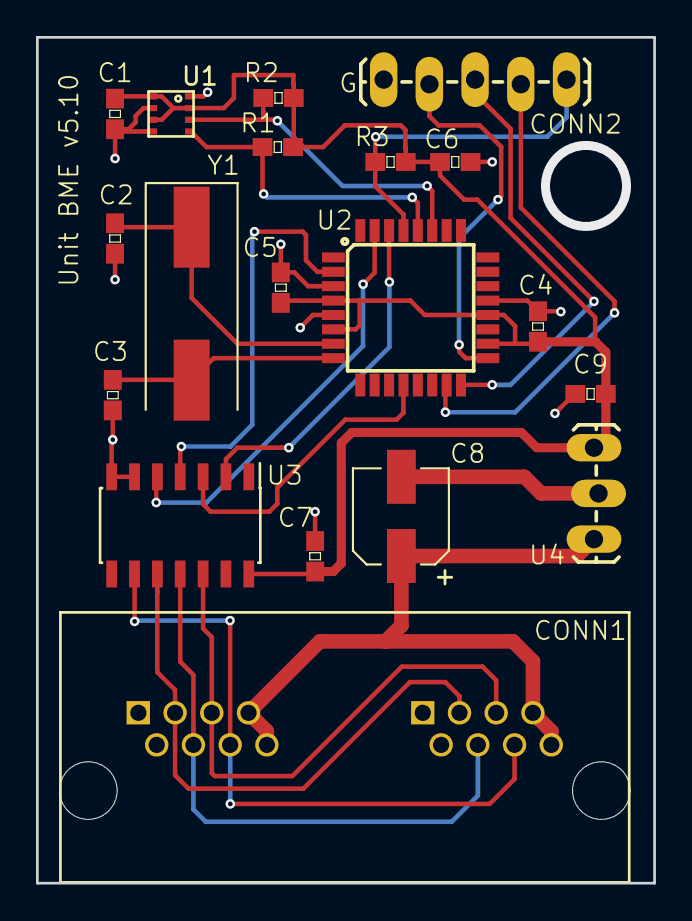
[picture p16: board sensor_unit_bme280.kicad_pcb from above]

Board: 2 copper layers, 34.3 x 47.0 mm, 19 parts (0 on the bottom side), 19 nets.

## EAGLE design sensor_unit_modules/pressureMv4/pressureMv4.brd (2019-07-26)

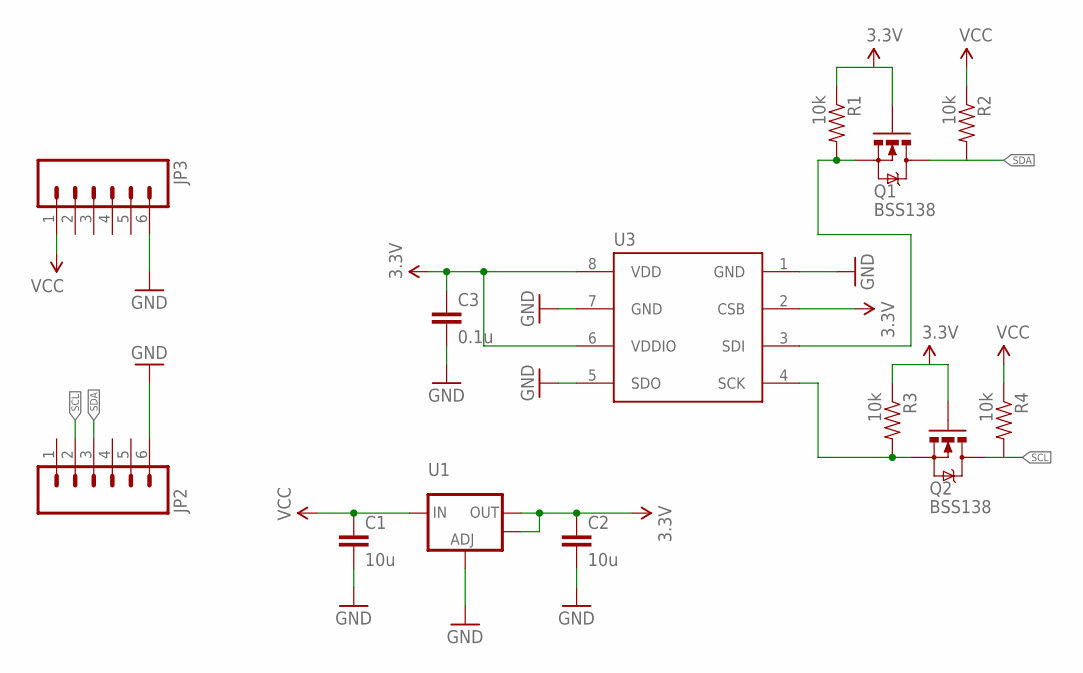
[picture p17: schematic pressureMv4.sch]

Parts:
C1, C2: 10u; 0805
C3: 0.1u; 0805
JP2, JP3: M06LOCK_LONGPADS; 1X06_LOCK_LONGPADS
Q1, Q2: BSS138; SOT323
R1, R2, R3, R4: 10k; 0805
U1: V_REG_LM1117SOT223; SOT223
U3: BME280SMD; BME280

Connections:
3.3V: C2.1, C3.1, Q1.1 (G), Q2.1 (G), R1.1, R3.1, U1.2 (OUT), U1.4 (OUT), U3.2 (CSB), U3.6 (VDDIO), U3.8 (VDD)
GND: C1.2, C2.2, C3.2, JP2.6, JP3.6, U1.1 (ADJ), U3.1 (GND), U3.5 (SDO), U3.7 (GND)
unnamed: Q1.2 (S), R1.2, U3.3 (SDI)
unnamed: Q2.2 (S), R3.2, U3.4 (SCK)
SCL: JP2.2, Q2.3 (D), R4.2
SDA: JP2.3, Q1.3 (D), R2.2
VCC: C1.1, JP3.1, R2.1, R4.1, U1.3 (IN)

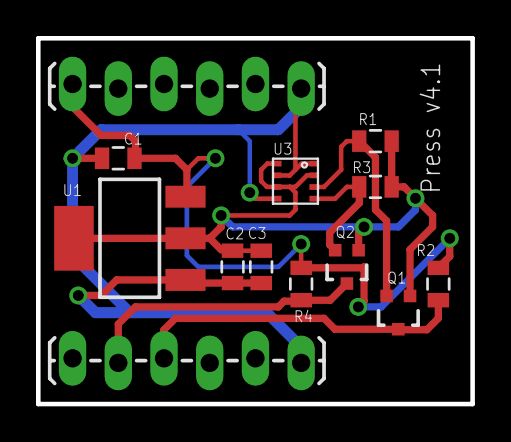
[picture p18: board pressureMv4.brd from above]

Board: 2 copper layers, 24.1 x 20.3 mm, 13 parts (0 on the bottom side), 7 nets.

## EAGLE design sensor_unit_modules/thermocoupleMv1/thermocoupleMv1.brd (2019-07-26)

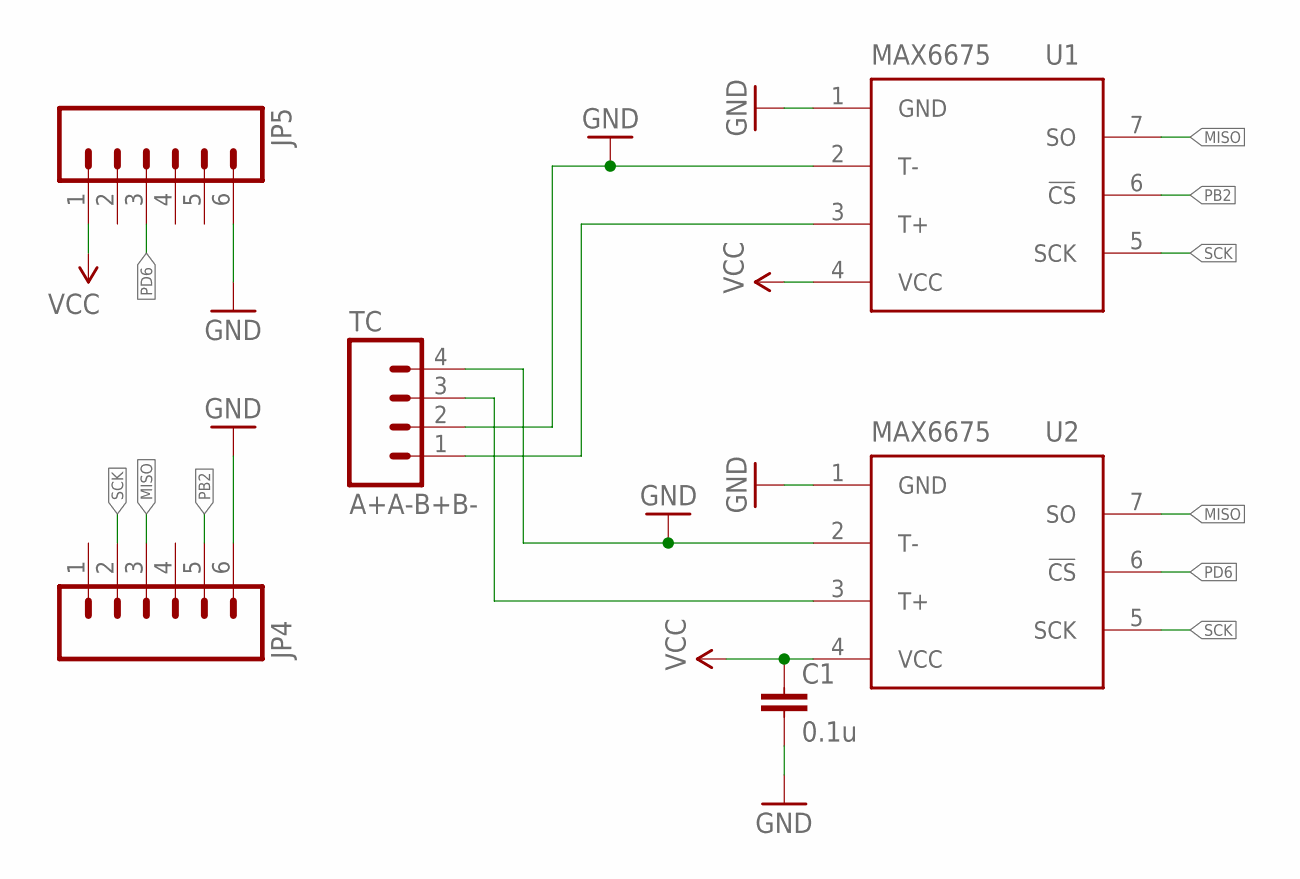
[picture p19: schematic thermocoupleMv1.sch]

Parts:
C1: 0.1u; 0805
JP4, JP5: M06LOCK_LONGPADS; 1X06_LOCK_LONGPADS
TC: A+A-B+B-; 1X04_LOCK_LONGPADS
U1, U2: MAX6675; SO08

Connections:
GND: C1.2, JP4.6, JP5.6, TC.2, TC.4, U1.1 (GND), U1.2 (T-), U2.1 (GND), U2.2 (T-)
MISO: JP4.3, U1.7 (SO), U2.7 (SO)
unnamed: TC.1, U1.3 (T+)
unnamed: TC.3, U2.3 (T+)
PB2: JP4.5, U1.6 (!CS)
PD6: JP5.3, U2.6 (!CS)
SCK: JP4.2, U1.5 (SCK), U2.5 (SCK)
VCC: C1.1, JP5.1, U1.4 (VCC), U2.4 (VCC)

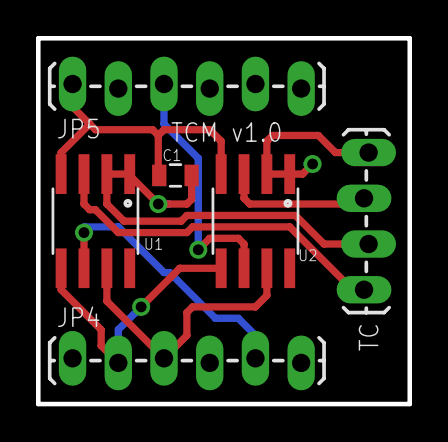
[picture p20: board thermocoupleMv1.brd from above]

Board: 2 copper layers, 20.6 x 20.3 mm, 6 parts (0 on the bottom side), 8 nets.

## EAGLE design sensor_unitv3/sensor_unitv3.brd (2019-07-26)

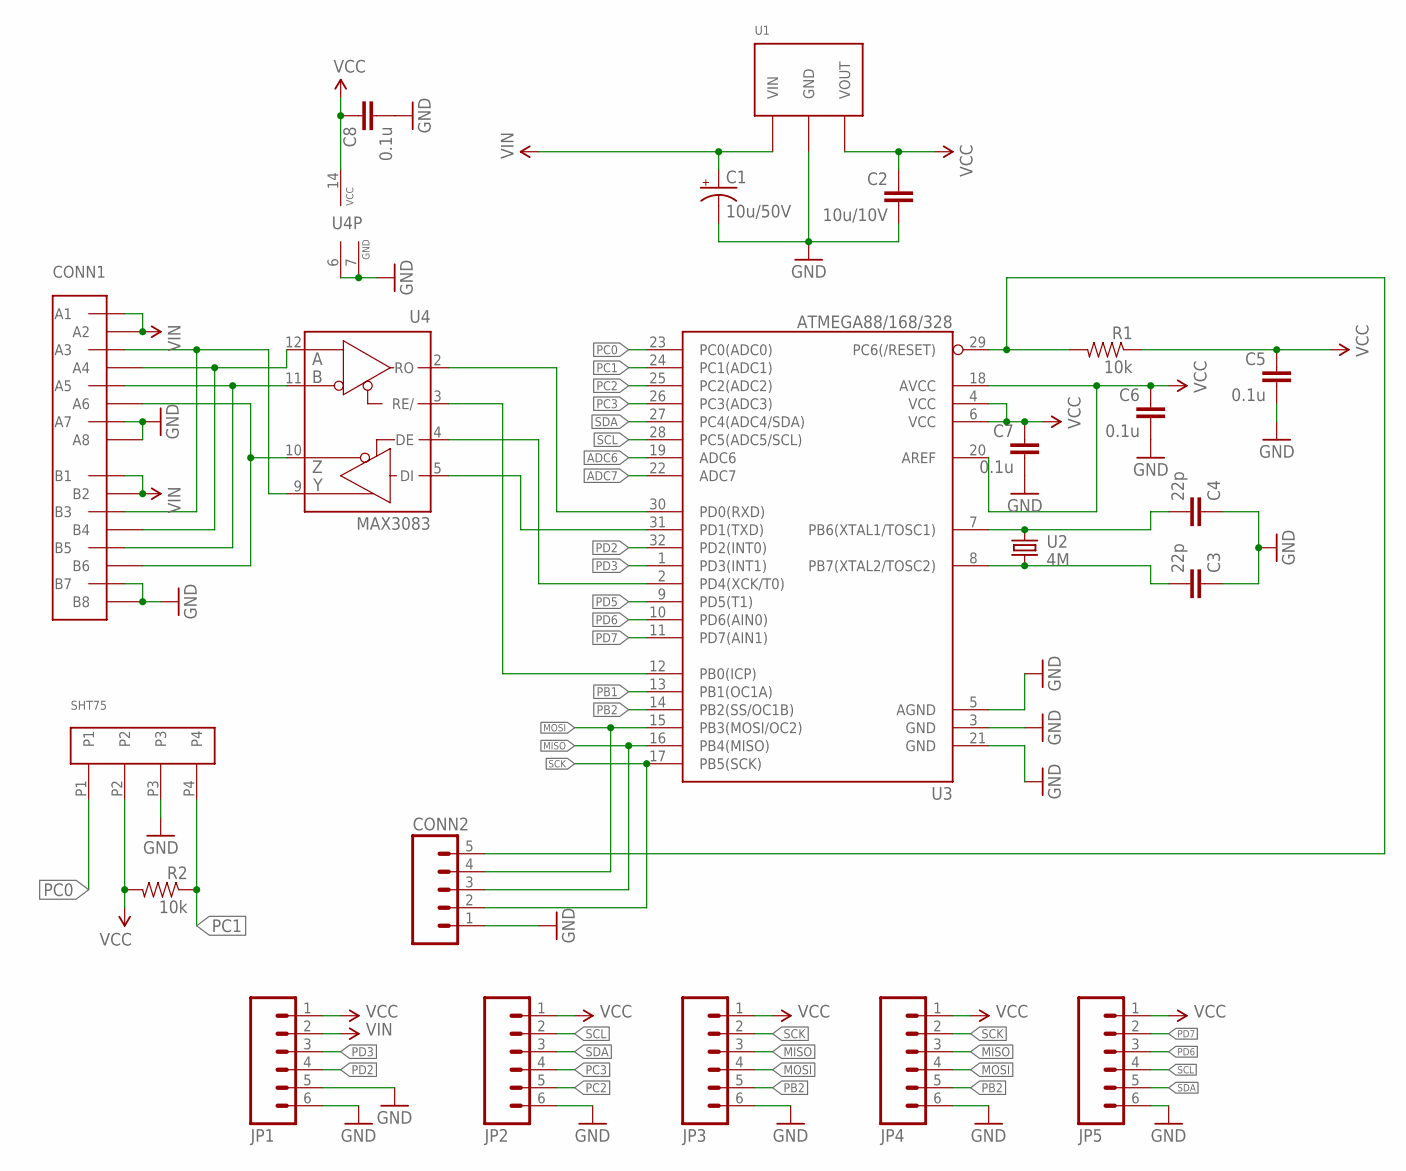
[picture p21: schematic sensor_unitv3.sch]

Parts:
C1: 10u/50V; PANASONIC_C
C2: 10u/10V; 0805
C3, C4: 22p; 0805
C5, C6, C7, C8: 0.1u; 0805
CONN1: 4UCON-04950
CONN2: M05LOCK; 1X05_LOCK
JP1, JP2, JP3, JP4, JP5: M06LOCK_LONGPADS; 1X06_LOCK_LONGPADS
R1, R2: 10k; 0805
SHT75: MM852-43-004-20; MM851-43-004-20
U1: OKI-78SR
U2: 4M; HC49UP
U3: ATMEGA88/168/328; TQFP32-08
U4: MAX3083; SO14

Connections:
ADC6: U3.19 (ADC6)
ADC7: U3.22 (ADC7)
C1U49: CONN1.A3, CONN1.B3, U4.9 (Y)
DE: U3.2 (PD4(XCK/T0)), U4.4 (DE)
DI: U3.31 (PD1(TXD)), U4.5 (DI)
GND: C1.-, C2.2, C3.1, C4.1, C5.2, C6.2, C7.2, C8.2, CONN1.A7, CONN1.A8, CONN1.B7, CONN1.B8, CONN2.1, JP1.5, JP1.6, JP2.6, JP3.6, JP4.6, JP5.6, SHT75.P3, U1.GND, U3.3 (GND), U3.5 (AGND), U3.21 (GND), U4.6 (GND), U4.7 (GND)
MISO: CONN2.3, JP3.3, JP4.3, U3.16 (PB4(MISO))
MOSI: CONN2.4, JP3.4, JP4.4, U3.15 (PB3(MOSI/OC2))
unnamed: C3.2, U2.1, U3.8 (PB7(XTAL2/TOSC2))
unnamed: C4.2, U2.2, U3.7 (PB6(XTAL1/TOSC1))
unnamed: CONN1.A5, CONN1.B5, U4.11 (B)
unnamed: CONN1.A4, CONN1.B4, U4.12 (A)
unnamed: CONN1.A6, CONN1.B6, U4.10 (Z)
PB1: U3.13 (PB1(OC1A))
PB2: JP3.5, JP4.5, U3.14 (PB2(SS/OC1B))
PC0: SHT75.P1, U3.23 (PC0(ADC0))
PC1: R2.1, SHT75.P4, U3.24 (PC1(ADC1))
PC2: JP2.5, U3.25 (PC2(ADC2))
PC3: JP2.4, U3.26 (PC3(ADC3))
PD2: JP1.4, U3.32 (PD2(INT0))
PD3: JP1.3, U3.1 (PD3(INT1))
PD5: U3.9 (PD5(T1))
PD6: JP5.3, U3.10 (PD6(AIN0))
PD7: JP5.2, U3.11 (PD7(AIN1))
RE: U3.12 (PB0(ICP)), U4.3 (RE/)
RESET: CONN2.5, R1.2, U3.29 (PC6(/RESET))
RO: U3.30 (PD0(RXD)), U4.2 (RO)
SCK: CONN2.2, JP3.2, JP4.2, U3.17 (PB5(SCK))
SCL: JP2.2, JP5.4, U3.28 (PC5(ADC5/SCL))
SDA: JP2.3, JP5.5, U3.27 (PC4(ADC4/SDA))
VCC: C2.1, C5.1, C6.1, C7.1, C8.1, JP1.1, JP2.1, JP3.1, JP4.1, JP5.1, R1.1, R2.2, SHT75.P2, U1.VOUT, U3.4 (VCC), U3.6 (VCC), U3.18 (AVCC), U3.20 (AREF), U4.14 (VCC)
VIN: C1.+, CONN1.A1, CONN1.A2, CONN1.B1, CONN1.B2, JP1.2, U1.VIN

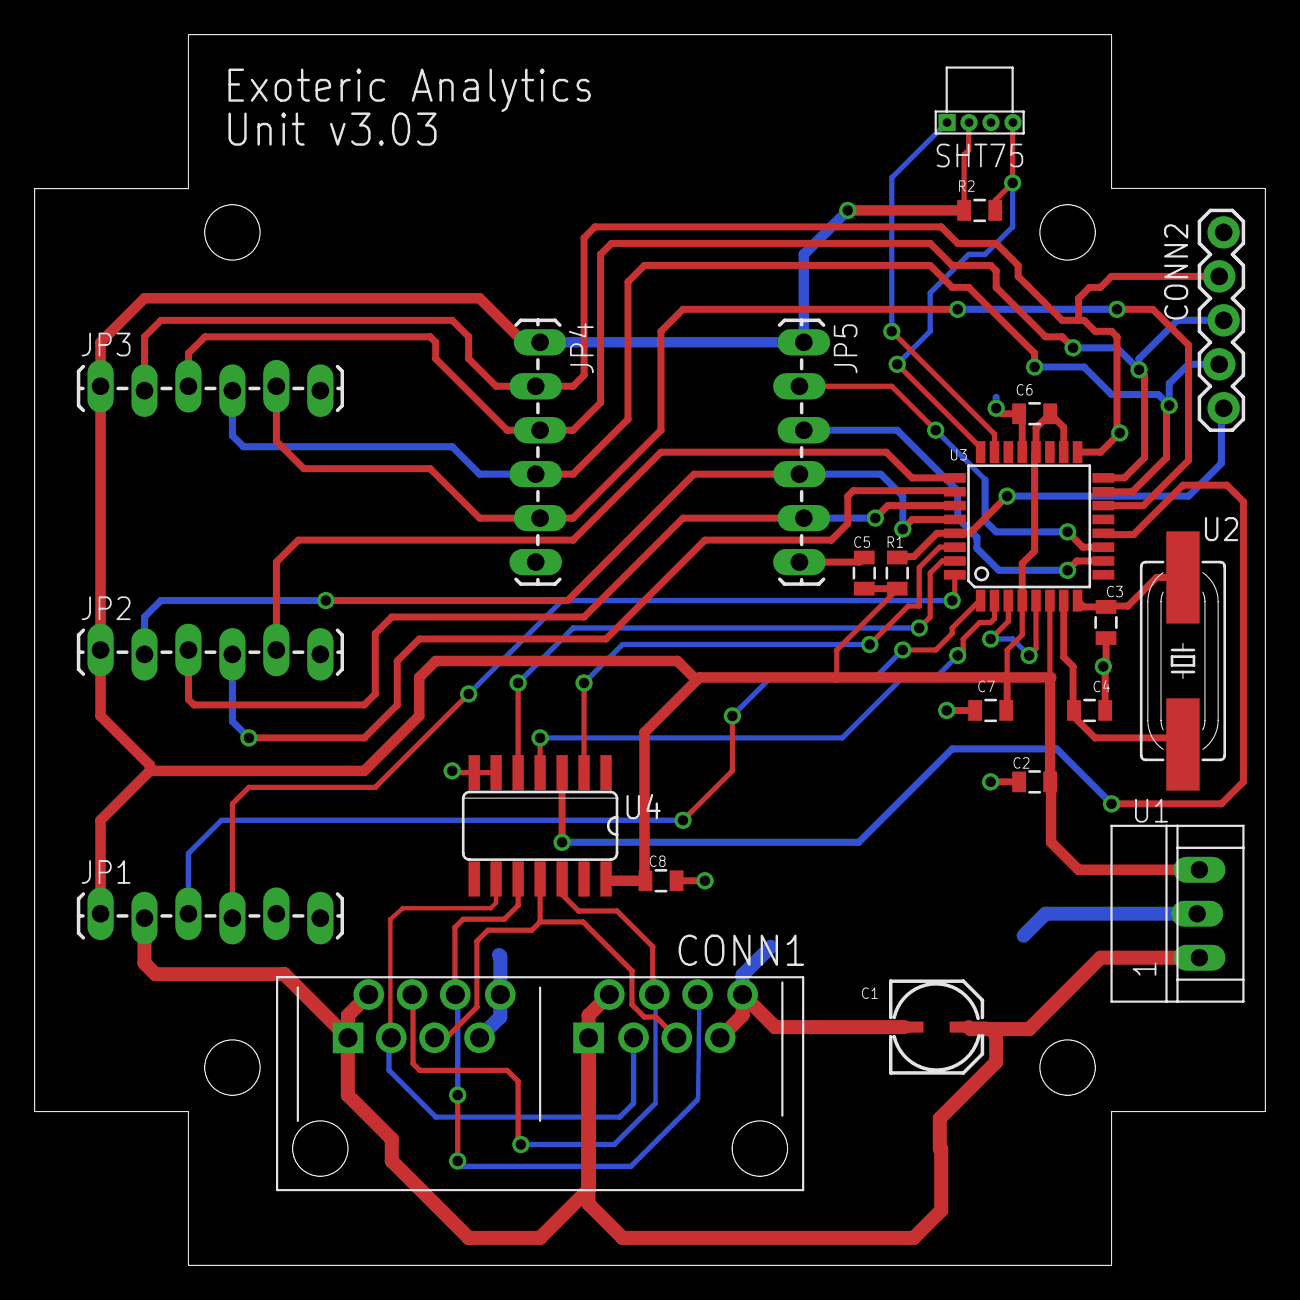
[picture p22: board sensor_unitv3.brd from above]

Board: 2 copper layers, 71.1 x 71.1 mm, 22 parts (0 on the bottom side), 28 nets.

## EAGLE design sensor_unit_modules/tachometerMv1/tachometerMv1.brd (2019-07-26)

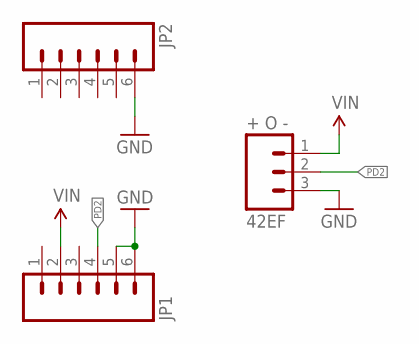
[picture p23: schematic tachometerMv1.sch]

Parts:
42EF: + O -; 1X03_LOCK_LONGPADS
JP1, JP2: M06LOCK_LONGPADS; 1X06_LOCK_LONGPADS

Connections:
GND: 42EF.3, JP1.5, JP1.6, JP2.6
PD2: 42EF.2, JP1.4
VIN: 42EF.1, JP1.2

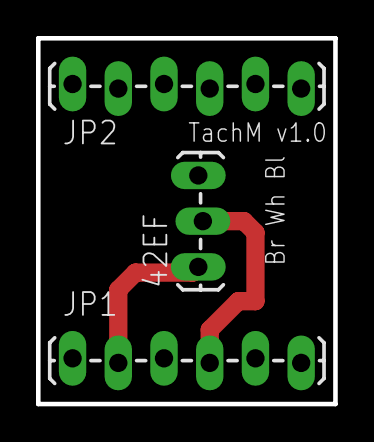
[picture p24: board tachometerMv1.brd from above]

Board: 2 copper layers, 16.5 x 20.3 mm, 3 parts (0 on the bottom side), 3 nets.

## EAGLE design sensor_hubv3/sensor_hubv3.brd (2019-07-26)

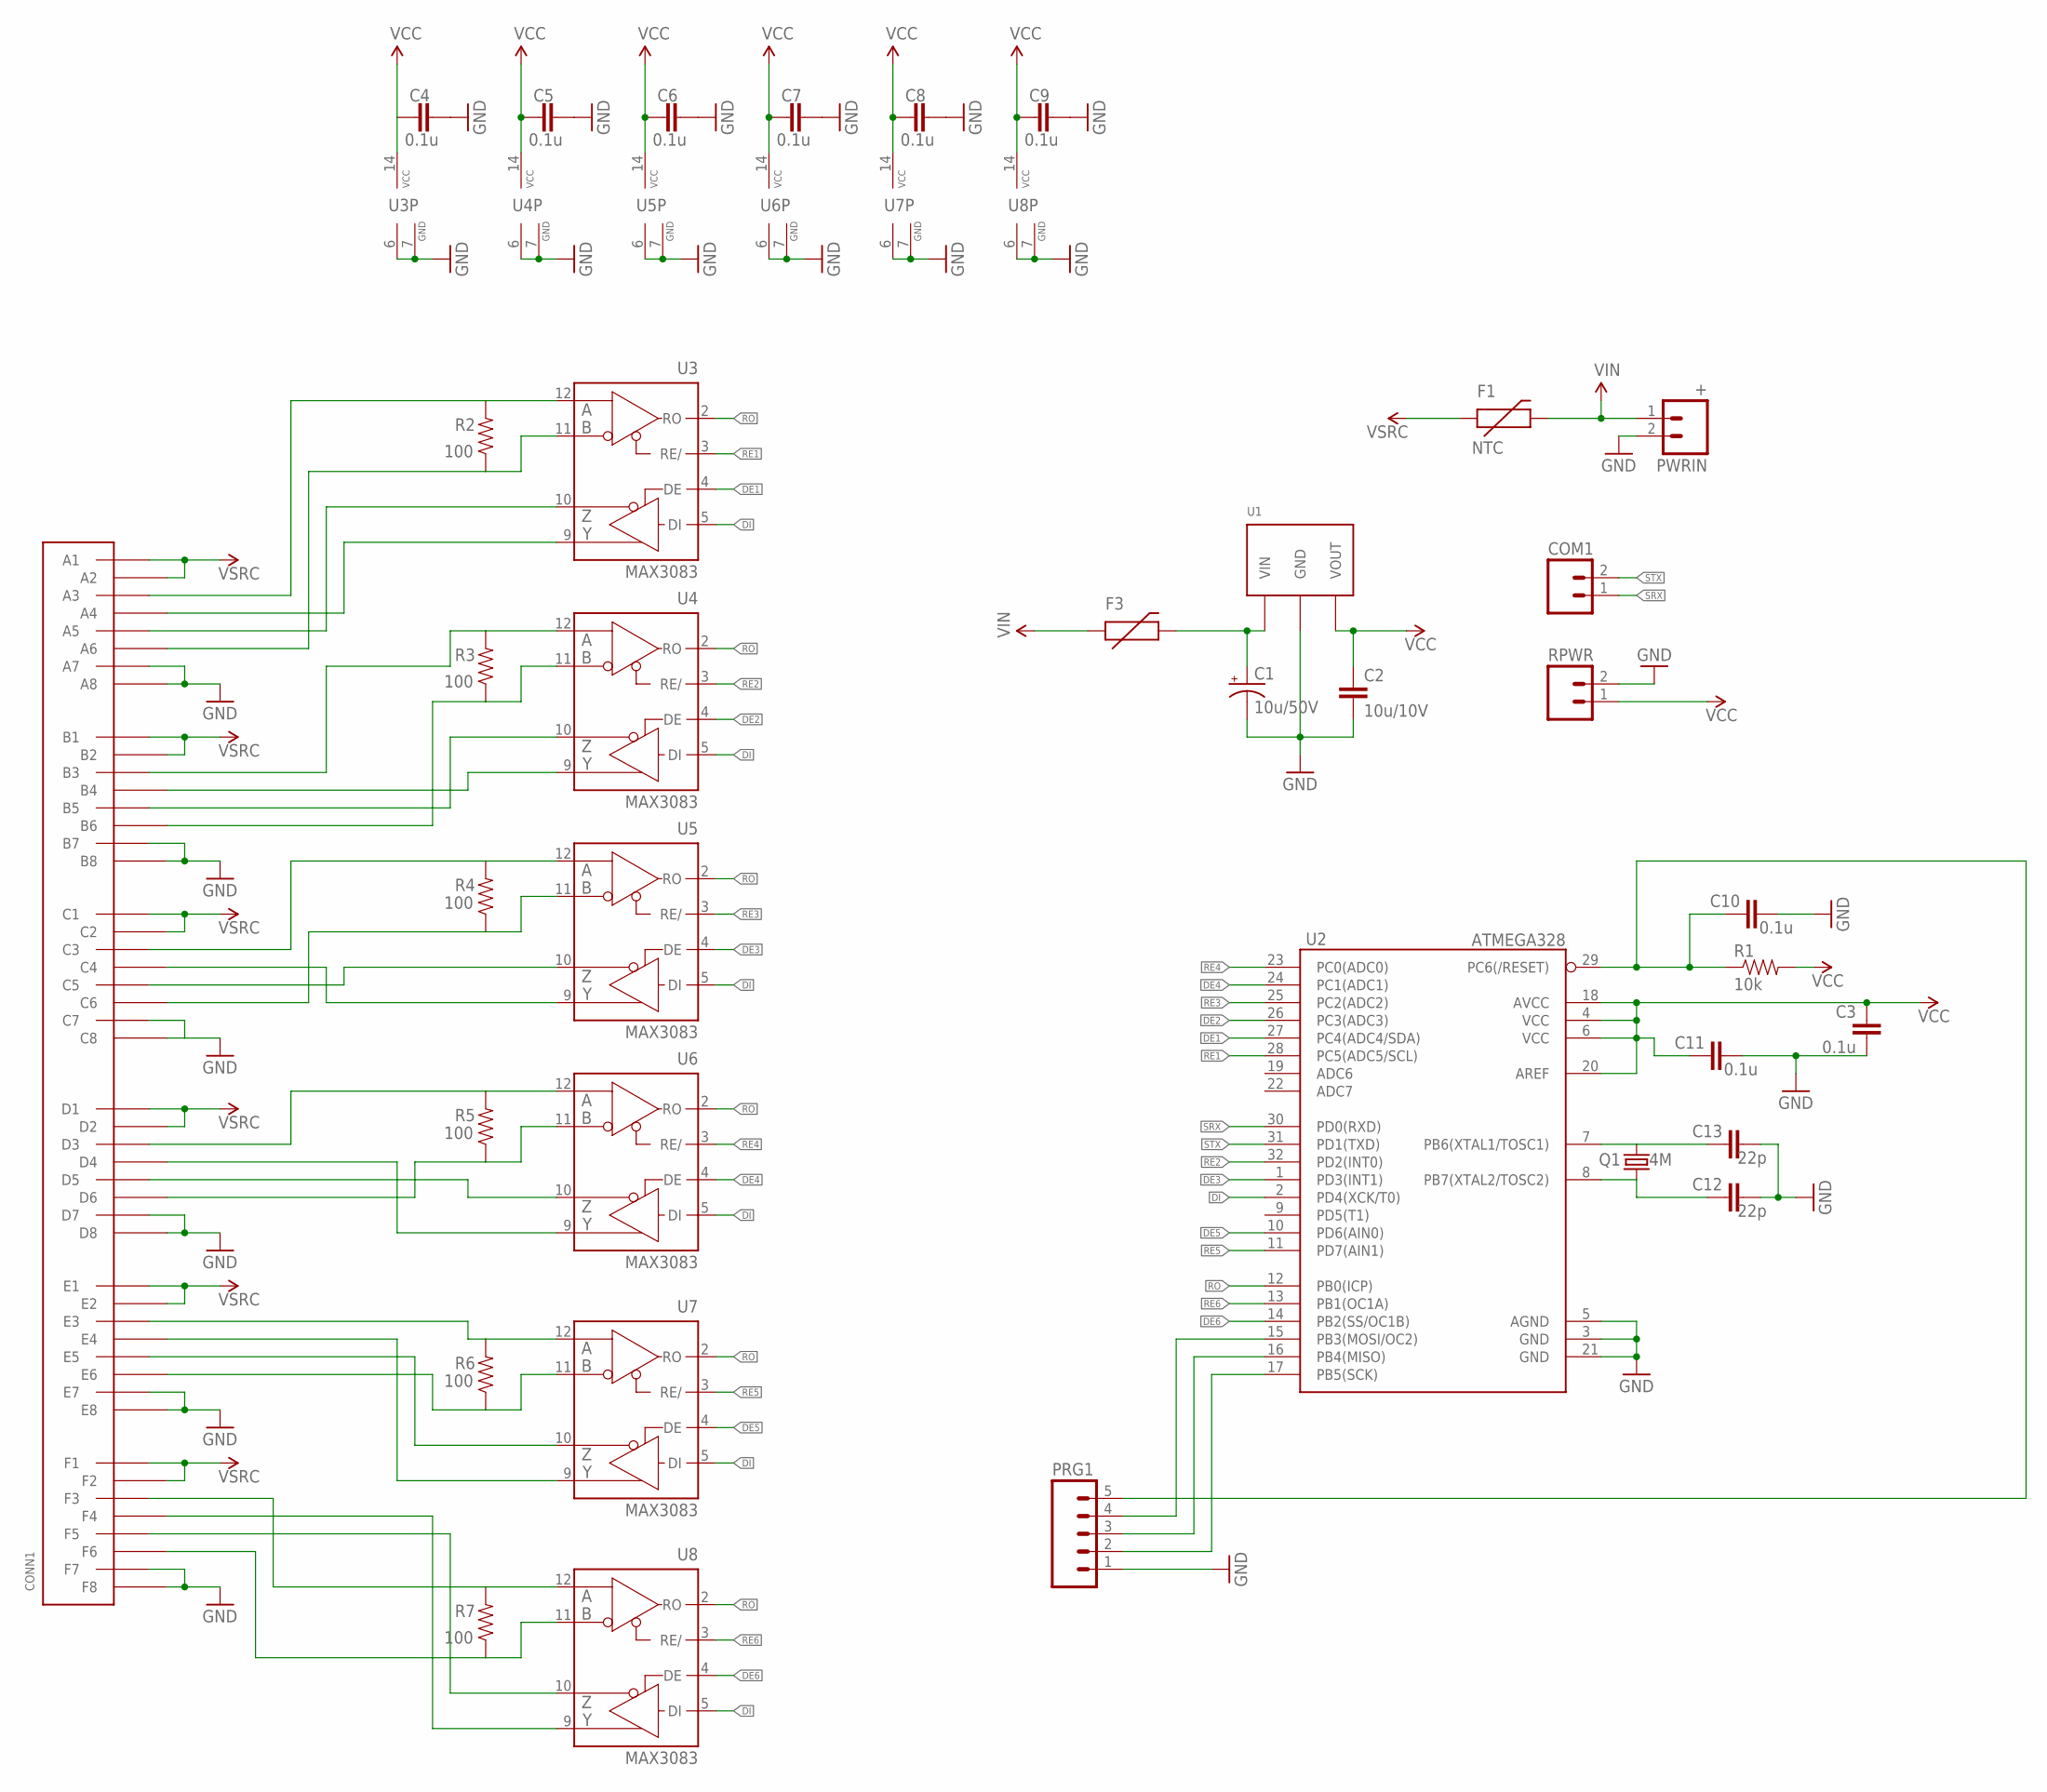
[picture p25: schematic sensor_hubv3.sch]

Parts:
C1: 10u/50V; PANASONIC_C
C2: 10u/10V; 0805
C3, C4, C5, C6, C7, C8, C9, C10, C11: 0.1u; 0805
C12, C13: 22p; 0805
COM1: M02LOCK_LONGPADS; 1X02_LOCK_LONGPADS
CONN1: 8P8C-6PORT; 4UCON-04953
F1: NTC; R-7,5
F3: PTC0603; 0603
PRG1: M05LOCK; 1X05_LOCK
PWRIN: +; SCREWTERMINAL-5MM-2
Q1: 4M; HC49UP
R1: 10k; 0805
R2, R3, R4, R5, R6, R7: 100; 0805
RPWR: M02LOCK_LONGPADS; 1X02_LOCK_LONGPADS
U1: OKI-78SR
U2: ATMEGA328; TQFP32-08
U3, U4, U5, U6, U7, U8: MAX3083; SO14

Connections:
DE1: U2.27 (PC4(ADC4/SDA)), U3.4 (DE)
DE2: U2.26 (PC3(ADC3)), U4.4 (DE)
DE3: U2.1 (PD3(INT1)), U5.4 (DE)
DE4: U2.24 (PC1(ADC1)), U6.4 (DE)
DE5: U2.10 (PD6(AIN0)), U7.4 (DE)
DE6: U2.14 (PB2(SS/OC1B)), U8.4 (DE)
DI: U2.2 (PD4(XCK/T0)), U3.5 (DI), U4.5 (DI), U5.5 (DI), U6.5 (DI), U7.5 (DI), U8.5 (DI)
GND: C1.-, C2.2, C3.1, C4.2, C5.2, C6.2, C7.2, C8.2, C9.2, C10.2, C11.2, C12.2, C13.2, CONN1.A7, CONN1.A8, CONN1.B7, CONN1.B8, CONN1.C7, CONN1.C8, CONN1.D7, CONN1.D8, CONN1.E7, CONN1.E8, CONN1.F7, CONN1.F8, PRG1.1, PWRIN.2, RPWR.2, U1.GND, U2.3 (GND), U2.5 (AGND), U2.21 (GND), U3.6 (GND), U3.7 (GND), U4.6 (GND), U4.7 (GND), U5.6 (GND), U5.7 (GND), U6.6 (GND), U6.7 (GND), U7.6 (GND), U7.7 (GND), U8.6 (GND), U8.7 (GND)
unnamed: CONN1.C4, U5.9 (Y)
unnamed: C13.1, Q1.2, U2.7 (PB6(XTAL1/TOSC1))
unnamed: C1.+, F3.2, U1.VIN
unnamed: C12.1, Q1.1, U2.8 (PB7(XTAL2/TOSC2))
unnamed: C10.1, PRG1.5, R1.1, U2.29 (PC6(/RESET))
unnamed: PRG1.4, U2.15 (PB3(MOSI/OC2))
unnamed: PRG1.3, U2.16 (PB4(MISO))
unnamed: PRG1.2, U2.17 (PB5(SCK))
unnamed: CONN1.A3, R2.2, U3.12 (A)
unnamed: CONN1.D6, R5.1, U6.11 (B)
unnamed: CONN1.C3, R4.2, U5.12 (A)
unnamed: CONN1.D3, R5.2, U6.12 (A)
unnamed: CONN1.E3, R6.2, U7.12 (A)
unnamed: CONN1.F3, R7.2, U8.12 (A)
unnamed: CONN1.A6, R2.1, U3.11 (B)
unnamed: CONN1.B6, R3.1, U4.11 (B)
unnamed: CONN1.C6, R4.1, U5.11 (B)
unnamed: CONN1.A5, U3.10 (Z)
unnamed: CONN1.E6, R6.1, U7.11 (B)
unnamed: CONN1.F6, R7.1, U8.11 (B)
unnamed: CONN1.B3, R3.2, U4.12 (A)
unnamed: CONN1.B5, U4.10 (Z)
unnamed: CONN1.C5, U5.10 (Z)
unnamed: CONN1.D5, U6.10 (Z)
unnamed: CONN1.E5, U7.10 (Z)
unnamed: CONN1.F5, U8.10 (Z)
unnamed: CONN1.A4, U3.9 (Y)
unnamed: CONN1.B4, U4.9 (Y)
unnamed: CONN1.D4, U6.9 (Y)
unnamed: CONN1.E4, U7.9 (Y)
unnamed: CONN1.F4, U8.9 (Y)
RE1: U2.28 (PC5(ADC5/SCL)), U3.3 (RE/)
RE2: U2.32 (PD2(INT0)), U4.3 (RE/)
RE3: U2.25 (PC2(ADC2)), U5.3 (RE/)
RE4: U2.23 (PC0(ADC0)), U6.3 (RE/)
RE5: U2.11 (PD7(AIN1)), U7.3 (RE/)
RE6: U2.13 (PB1(OC1A)), U8.3 (RE/)
RO: U2.12 (PB0(ICP)), U3.2 (RO), U4.2 (RO), U5.2 (RO), U6.2 (RO), U7.2 (RO), U8.2 (RO)
SRX: COM1.1, U2.30 (PD0(RXD))
STX: COM1.2, U2.31 (PD1(TXD))
VCC: C2.1, C3.2, C4.1, C5.1, C6.1, C7.1, C8.1, C9.1, C11.1, R1.2, RPWR.1, U1.VOUT, U2.4 (VCC), U2.6 (VCC), U2.18 (AVCC), U2.20 (AREF), U3.14 (VCC), U4.14 (VCC), U5.14 (VCC), U6.14 (VCC), U7.14 (VCC), U8.14 (VCC)
VIN: F1.P$2 (2), F3.1, PWRIN.1
VSRC: CONN1.A1, CONN1.A2, CONN1.B1, CONN1.B2, CONN1.C1, CONN1.C2, CONN1.D1, CONN1.D2, CONN1.E1, CONN1.E2, CONN1.F1, CONN1.F2, F1.P$1 (1)

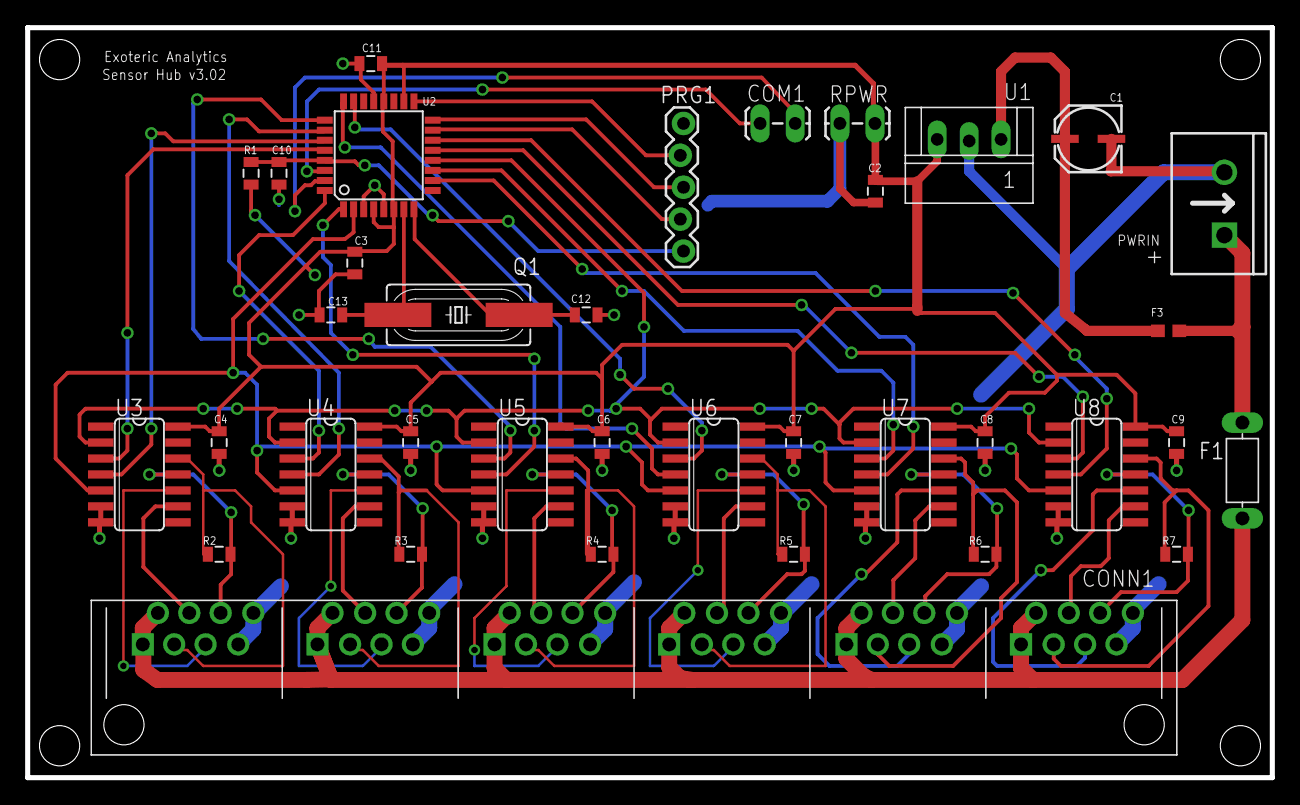
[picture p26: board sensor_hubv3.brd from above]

Board: 2 copper layers, 99.1 x 59.7 mm, 36 parts (0 on the bottom side), 51 nets.

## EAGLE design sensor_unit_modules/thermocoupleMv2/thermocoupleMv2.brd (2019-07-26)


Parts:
C1, C2, C3: 10u; 0805
C4: 0.1u; 0805
JP4, JP5: M06LOCK_LONGPADS; 1X06_LOCK_LONGPADS
R1, R2, R3, R4: 10k; 0805
TC: T+T-; 1X02_LOCK_LONGPADS
U1: V_REG_LM1117SOT223; SOT223
U2: MAX31855; SO08

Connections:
3.3V: C2.1, C4.1, U1.2 (OUT), U1.4 (OUT), U2.4 (VCC)
GND: C1.2, C2.2, C4.2, JP4.6, JP5.6, R2.2, R4.1, U1.1 (ADJ), U2.1 (GND)
MISO: JP4.3, U2.7 (SO)
unnamed: C3.2, TC.1, U2.3 (T+)
unnamed: R1.2, R2.1, U2.5 (SCK)
unnamed: C3.1, TC.2, U2.2 (T-)
unnamed: R3.2, R4.2, U2.6 (!CS)
PB2: JP4.5, R3.1
PD6: JP5.3
SCK: JP4.2, R1.1
VCC: C1.1, JP5.1, U1.3 (IN)


Board: 2 copper layers, 24.4 x 20.3 mm, 13 parts (0 on the bottom side), 10 nets.

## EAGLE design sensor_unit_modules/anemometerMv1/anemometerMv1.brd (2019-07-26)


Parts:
C1: 0.1uF; 0805-CAP
J1: M02LOCK_LONGPADS; 1X02_LOCK_LONGPADS
JP1, JP2: M06LOCK_LONGPADS; 1X06_LOCK_LONGPADS

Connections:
GND: C1.1, J1.1, JP1.5, JP1.6, JP2.6
PD2: C1.2, J1.2, JP1.4


Board: 2 copper layers, 16.5 x 20.3 mm, 4 parts (0 on the bottom side), 2 nets.

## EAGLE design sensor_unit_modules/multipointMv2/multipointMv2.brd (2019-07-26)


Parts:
C1: 0.1u; 0805
CONN1: - 4 3 2 1 +; 1X06_LOCK_LONGPADS
JP4, JP5: M06LOCK_LONGPADS; 1X06_LOCK_LONGPADS
R1, R2: 4.7k; 0805
U1: DS2482-800; SO16

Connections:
GND: C1.2, CONN1.6, JP4.6, JP5.6, U1.6 (AD2), U1.7 (AD1), U1.8 (AD0), U1.13 (GND)
unnamed: CONN1.5, U1.16 (IO2)
unnamed: CONN1.4, U1.15 (IO1)
unnamed: CONN1.3, U1.14 (IO0)
unnamed: CONN1.2, U1.12 (IO4)
unnamed: CONN1.1, JP5.1
SCL: JP5.4, R1.1, U1.2 (SCL)
SDA: JP5.5, R2.1, U1.3 (SDA)
VCC: C1.1, JP4.1, R1.2, R2.2, U1.4 (VCC)


Board: 2 copper layers, 25.1 x 20.3 mm, 7 parts (0 on the bottom side), 9 nets.

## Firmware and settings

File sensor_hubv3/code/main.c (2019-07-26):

//   Copyright 2010-2019 Dan Elliott, Russell Valentine
//
//   Licensed under the Apache License, Version 2.0 (the "License");
//   you may not use this file except in compliance with the License.
//   You may obtain a copy of the License at
//
//       http://www.apache.org/licenses/LICENSE-2.0
//
//   Unless required by applicable law or agreed to in writing, software
//   distributed under the License is distributed on an "AS IS" BASIS,
//   WITHOUT WARRANTIES OR CONDITIONS OF ANY KIND, either express or implied.
//   See the License for the specific language governing permissions and
//   limitations under the License.

#define BAUD 9600

#include <stdio.h>
#include <stdbool.h>

#include <avr/io.h>
#include <avr/interrupt.h>
#include <avr/pgmspace.h>
#include <avr/wdt.h>
#include <util/delay.h>
#include <util/setbaud.h>
#include <util/crc16.h>

#include "softuart.h"

#define REPLY_READINGS 1
#define REPLY_EXEC_SUCCESS 2
#define REPLY_PONG 3
#define REPLY_ERROR 4
#define REPLY_VERSION 5
#define REPLY_DONE 170

#define ERROR_BADADDRCOUNT 2
#define ERROR_UNITTIMEOUT 4
#define ERROR_BADCMDCODE 5
#define ERROR_BADCRC 6
#define ERROR_BADUNITRXSIZE 7
#define ERROR_MISSINGFEATURE 10

//Command codes
#define CC_TEMPHUM 1
#define CC_WIND 2
#define CC_TACH 3
#define CC_TTEMP 6
#define CC_PRESSURE 7
#define CC_GUNITREAD 25
#define CC_CALREAD 64
#define CC_CALSET 65
#define CC_CHANGEIP 128
#define CC_CHANGEMAC 129
#define CC_PING 130
#define CC_HUBVERSION 150

//UNIT Sizes for command codes
#define USIZE_TEMPHUM 4
#define USIZE_WIND 2
#define USIZE_TACH 2
#define USIZE_TTEMP 4
#define USIZE_PRESSURE 2

#define USIZE_MAX 8

#define HUB_VERSION 4


//#define DEBUG

#ifdef DEBUG
#define URX_TIMEOUT 40000 // 40000*1us=4s
#define ERX_TIMEOUT 10000 //10000*100us=1s
#else
#define URX_TIMEOUT 40000 // 40000*1us=4s
#define ERX_TIMEOUT 2500 //2500*100us=250ms
#endif

#define MAX_ADDR_COUNT 32 
#define STXBUFSIZE 7 // Standard Unit transmit 4magic+2addr+1cc 
#define GCALTXBUFSIZE 8 // size of get calibration unit transmit 4magic+2addr+1ccA+1ccB
#define SCALTXBUFSIZE_MAX 16 // max size of set calibration unit transmit 4magic+2addr+1ccA+1ccB+8USIZE_MAX
#define MAX_URXBUFSIZE 17   //4magic+2addr+1cc+1s+USIZE_MAX+1crc
#define PREDATA_URXBUFSIZE 8 //No CRC 4 magic + 2 addr+1cc+1s
#define MAX_ADDRS 32
#define MAGIC0 'D'
#define MAGIC1 'E'
#define MAGIC2 'R'
#define MAGIC3 'V'
#define MAGIC_SIZE 4

//RS485 enable pins
//Port 1
#define RSP1RE PC5
#define RSP1REPORT PORTC
#define RSP1REDDR DDRC
#define RSP1DE PC4
#define RSP1DEPORT PORTC
#define RSP1DEDDR DDRC

//Port 2
#define RSP2RE PD2
#define RSP2REPORT PORTD
#define RSP2REDDR DDRD
#define RSP2DE PC3
#define RSP2DEDDR DDRC
#define RSP2DEPORT PORTC

//Port 3
#define RSP3RE PC2
#define RSP3REPORT PORTC
#define RSP3REDDR DDRC
#define RSP3DE PD3
#define RSP3DEPORT PORTD
#define RSP3DEDDR DDRD

//Port 4
#define RSP4RE PC0
#define RSP4REPORT PORTC
#define RSP4REDDR DDRC
#define RSP4DE PC1
#define RSP4DEPORT PORTC
#define RSP4DEDDR DDRC

//Port 5
#define RSP5RE PD7
#define RSP5REPORT PORTD
#define RSP5REDDR DDRD
#define RSP5DE PD6
#define RSP5DEPORT PORTD
#define RSP5DEDDR DDRD

//Port 6
#define RSP6RE PB1
#define RSP6REPORT PORTB
#define RSP6REDDR DDRB
#define RSP6DE PB2
#define RSP6DEPORT PORTB
#define RSP6DEDDR DDRB

static void ioinit(void);
static void* mymemcpy(void *dest, const void *src, size_t count);
static int uart_putchar(char c, FILE *stream);
static uint8_t uart_getchar(void);

static void uart_rxflush(void);
static uint8_t uart_kbhit(void);
static int swuart_putchar( char c, FILE *stream );
static bool check_magic(uint8_t c, uint8_t idx);
static void disable_rsports(void);
static void enable_rsport(uint8_t port);
static bool query_unit(uint16_t addr);
static bool good_crc(uint8_t);
static void get_send_sensor_data(uint8_t);
static void send_errors_data(uint8_t errors[], uint16_t errors_size, uint8_t data[], uint16_t data_size);
static void send_error_reply_only(uint8_t code, uint8_t addrIdx);
static void eth_input(uint8_t c);
static void unit_input(uint8_t c, uint16_t addr);
static void send_pong(uint16_t ping);
static void send_version(void);

static FILE mystdout = FDEV_SETUP_STREAM(uart_putchar, NULL, _FDEV_SETUP_WRITE);
static FILE suart_stream = FDEV_SETUP_STREAM(swuart_putchar, NULL, _FDEV_SETUP_WRITE );

//Variable for recieving data from unit
static uint8_t volatile urxbuffer[MAX_URXBUFSIZE];
static uint8_t volatile urxidx=0;
static bool volatile urxdone=false;

//Variables from recieving data from ethernet board
static uint8_t volatile cmd_code; //Command code
static uint8_t volatile cmd_codep; //Unit command code for batched commands.
static uint8_t volatile cmd_codeo; //Original command code for batched commands.
static uint8_t volatile cmd_size;
static uint8_t volatile cmd_port;
static uint16_t volatile cmd_addrs[MAX_ADDRS];
static uint8_t volatile cmd_cal_set[USIZE_MAX];
static uint8_t volatile cmd_cal_setcount=0;
static uint8_t volatile erxcount=0;
static uint16_t volatile erxtimeout=0;
static uint8_t volatile erxaddrcount=0;
static bool volatile activate=false;


int main(void)
{
	ioinit();
#ifdef DEBUG
	printf("DEBUG: Starting hub\r\n");
#endif
	for (;;)
	{
		if(activate)
		{
			//XXX: Check cmd_port for other commands besides 1-4
			//DEBUG:
#ifdef DEBUG
			printf("DEBUG: Got activate\r\n");
#endif
			if(cmd_code == CC_TEMPHUM)
			{
				cmd_size = USIZE_TEMPHUM;
				get_send_sensor_data(USIZE_TEMPHUM); 
			} 
			else if(cmd_code == CC_WIND)
			{
				cmd_size = USIZE_WIND;
				get_send_sensor_data(USIZE_WIND); 
			}
			else if(cmd_code == CC_TACH)
			{
				cmd_size = USIZE_TACH;
				get_send_sensor_data(USIZE_TACH); 
			}
			else if(cmd_code == CC_TTEMP)
			{
				cmd_size = USIZE_TTEMP;
				get_send_sensor_data(USIZE_TTEMP); 
			}
			else if(cmd_code == CC_PRESSURE)
			{
				cmd_size = USIZE_PRESSURE;
				get_send_sensor_data(USIZE_PRESSURE); 
			}
			else if(cmd_code == CC_PING)
			{
				send_pong(cmd_addrs[0]);
			} 
			else if(cmd_code == CC_HUBVERSION) {
				send_version();
			}
			else if(cmd_code == CC_GUNITREAD || cmd_code == CC_CALREAD || cmd_code == CC_CALSET)
			{
				cmd_code = cmd_codep;
				get_send_sensor_data(cmd_size);
			}
			else
			{

#ifdef DEBUG
				printf("DEBUG: Got bad command code.\r\n");
#endif
				send_error_reply_only(ERROR_BADCMDCODE, 0);
				erxcount=0;
			}
			activate=false;
		}
		if(erxcount >= MAGIC_SIZE && erxtimeout > ERX_TIMEOUT) //If we got magic but they never finished
		{
#ifdef DEBUG
			printf("DEBUG: Got timeout after magic, erxcount=%d.\r\n", erxcount);
#endif
			send_error_reply_only(ERROR_BADADDRCOUNT, 0);
			erxcount=0;
		}
		if(uart_kbhit())
		{
			eth_input(uart_getchar());
		}
		_delay_us(100);
		wdt_reset(); //Watchdog timer reset
		erxtimeout++;
	}
	return 0;
}

/*
 * Ask a unit for it's data.
 */
bool query_unit(uint16_t addr)
{
	uint8_t stxbuffer[SCALTXBUFSIZE_MAX];
	uint8_t bufsize = STXBUFSIZE;
	uint16_t timeout=0;
#ifdef DEBUG
	printf("DEBUG: Querying addr: %d, cmd_code: %d\r\n", addr, cmd_code);
#endif

	stxbuffer[0]=MAGIC0;
	stxbuffer[1]=MAGIC1;
	stxbuffer[2]=MAGIC2;
	stxbuffer[3]=MAGIC3;
	mymemcpy(&stxbuffer[MAGIC_SIZE], &addr, 2); //Copy i'th address to buffer
	if(cmd_codeo == CC_CALREAD) {
		stxbuffer[6]=cmd_codeo;
		stxbuffer[7]=cmd_code;
		bufsize = GCALTXBUFSIZE;
	} else if(cmd_codeo == CC_CALSET) {
		stxbuffer[6]=cmd_codeo;
		stxbuffer[7]=cmd_code;
		mymemcpy(&stxbuffer[8], (void*)&cmd_cal_set[0], cmd_size);
		bufsize = GCALTXBUFSIZE+cmd_size;
	} else {
		stxbuffer[6]=cmd_code;
		bufsize = STXBUFSIZE;
	}

	//Reset Unit RX variables
	urxdone=false;
	urxidx=0;
	softuart_flush_input_buffer(); //Flush recieve buffer.
	_delay_ms(1);

	fwrite(stxbuffer, bufsize, 1, stderr); //Send request to sensor unit
	while(timeout < URX_TIMEOUT && !urxdone)
	{
		if(softuart_kbhit())
		{
			unit_input(softuart_getchar(), addr);
		}
		_delay_us(100);
		timeout++;
	}

	if(!urxdone)
	{
#ifdef DEBUG
		printf("DEBUG: Unit timedout, idx=%d\r\n", urxidx);
		//fwrite(urxbuffer, urxidx-1, 1, stdout);
#endif
		return false;
	}
	return true;
}

bool good_crc(uint8_t data_size)
{
	uint8_t gcrc=urxbuffer[PREDATA_URXBUFSIZE+data_size];
	uint8_t crc=0;
	uint8_t p=0;

	for( p = 0; p < PREDATA_URXBUFSIZE+data_size; p++)
	{
		crc = _crc_ibutton_update(crc, urxbuffer[p]);
	}
	if(crc != gcrc)
	{
#ifdef DEBUG
		printf("DEBUG: calc_crc=%d, urcr=%d\r\n", crc, gcrc);
#endif
		return false;
	}
	return true;
}

void send_pong(uint16_t ping)
{
	uint8_t txbuffer[3];


#ifdef DEBUG
	printf("DEBUG: send_pong called\r\n");
#endif

	txbuffer[0]=REPLY_PONG;
	ping++;
	mymemcpy(&txbuffer[1], &ping, 2);
	send_errors_data(0, 0, txbuffer, sizeof(txbuffer));
}

void send_version()
{
	uint8_t txbuffer[3];
	uint16_t version = HUB_VERSION;


#ifdef DEBUG
	printf("DEBUG: send_version called\r\n");
#endif

	txbuffer[0]=REPLY_VERSION;
	mymemcpy(&txbuffer[1], &version, 2);
	send_errors_data(0, 0, txbuffer, sizeof(txbuffer));
}



/*
 * Get sensor data from port and send it to ethernet board.
 */
void get_send_sensor_data(uint8_t ex_dsize)
{

	uint8_t txbuffer[4+ex_dsize*erxaddrcount];
	uint8_t i=0;
	uint16_t addr;

	bool error=false;
	uint8_t error_count=0;
	uint8_t txerrors[2+MAX_ADDR_COUNT*2];
	uint8_t rxdata_size = 0;

#ifdef DEBUG
	printf("DEBUG: get_send_sensor_data called\r\n");
#endif

	txbuffer[0]=REPLY_READINGS;  // Reply code
	txbuffer[1]=erxaddrcount * ex_dsize + 1; // S
	if(cmd_codeo == 64 || cmd_codeo == 65) {
		txbuffer[2]=cmd_codeo;
	} else {
		txbuffer[2]=cmd_code;   // CC
	}

	txbuffer[3]=erxaddrcount; // N
	txerrors[0]=REPLY_ERROR; // Reply code

	enable_rsport(cmd_port);
	//For each address send a sensor request and listen for reply.
	for(i=0; i < erxaddrcount; i++)
	{
		error=false;

		addr=cmd_addrs[i];
		if(!query_unit(addr))
		{
			//UNIT timed out
			txerrors[2+error_count*2]=ERROR_UNITTIMEOUT;
			txerrors[2+error_count*2+1]=(i+1);
			error_count++;
			error=true;
		} else {
			rxdata_size = urxbuffer[7];
		}

		//Check crc
		if(!error)
		{
			if(!good_crc(rxdata_size))
			{
				//CRC Error
#ifdef DEBUG
				printf("DEBUG: Bad crc\r\n");
#endif
				txerrors[2+error_count*2]=ERROR_BADCRC;
				txerrors[2+error_count*2+1]=(i+1);
				error_count++;
				error=true;
			}
		}

		if(!error)
		{
			if(rxdata_size == 0) 
			{
				//bad feature
#ifdef DEBUG
				printf("DEBUG: Unit missing feature\r\n");
#endif
				txerrors[2+error_count*2]=ERROR_MISSINGFEATURE;
				txerrors[2+error_count*2+1]=(i+1);
				error_count++;
				error=true;
			}
		}


		if(!error)
		{
			if(rxdata_size != ex_dsize) 
			{
				//Bad unit rx size
#ifdef DEBUG
				printf("DEBUG: Bad unit rx size\r\n");
#endif
				txerrors[2+error_count*2]=ERROR_BADUNITRXSIZE;
				txerrors[2+error_count*2+1]=(i+1);
				error_count++;
				error=true;
			}
		}

		if(!error)
		{
			//Add data to send package
			mymemcpy(&txbuffer[4+i*ex_dsize], (void*)&urxbuffer[8], ex_dsize);
		}
		else //There was a error, set data to zeros for that unit.
		{
#ifdef DEBUG
			printf("DEBUG: Zeroing unit data because of errors.\n\r");
#endif
			for(int n = 0; n < ex_dsize; n++)
			{
				txbuffer[4+i*ex_dsize+n]=0;
			}
		}
		wdt_reset(); //Reset watchdog timer
	}
	disable_rsports(); //We are done with the Port

	//Send any errors
	if(error_count)
	{
		txerrors[1]=error_count;
	}
	//Bytes in txerrors
	if(error_count > 0)
	{
		error_count=2+2*error_count;
	}
	//Send error and data
	send_errors_data(txerrors, error_count, txbuffer, sizeof(txbuffer));
}

/**
 * Send error and other data reply.
 */
void send_errors_data(uint8_t errors[], uint16_t errors_size, uint8_t data[], uint16_t data_size)
{
	uint16_t s = errors_size+data_size+2;

#ifdef DEBUG
	printf("DEBUG: send_errors_data called\r\n");
#endif
	fwrite(&s, sizeof(s), 1, stdout);
	if(errors_size)
	{
		fwrite(errors, errors_size, 1, stdout);
	}
	if(data_size)
	{
		fwrite(data, data_size, 1, stdout);
	}
}


/**
 * Send single error reply, then done.
 */
void send_error_reply_only(uint8_t code, uint8_t addrIdx)
{
	uint8_t error_buf[4];
	uint8_t d[1];

#ifdef DEBUG
	printf("DEBUG: send_error_reply_only called\r\n");
#endif

	error_buf[0]=REPLY_ERROR; //Reply Code
	error_buf[1]=1; //L
	error_buf[2]=code; //C_X
	error_buf[3]=code; //A_X
	send_errors_data(error_buf, 4, d, 0);
}


//Input from HW RX USART, from Ethernet board
void eth_input(uint8_t c)
{

	if(!activate)
	{
		if(erxcount < MAGIC_SIZE && check_magic(c, erxcount))
		{
			erxcount++;
			erxtimeout=0;
			return;
		}
		else if(erxcount < MAGIC_SIZE && erxcount != 0)
		{
			erxcount = 0;
			eth_input(c);
			return;
		}
		if(erxcount == MAGIC_SIZE)
		{
			cmd_codeo=c;
			cmd_code=c;
			erxcount++;
			erxtimeout=0;
			return;
		}

		if(cmd_code != CC_GUNITREAD && cmd_code != CC_CALREAD && cmd_code != CC_CALSET && erxcount >= MAGIC_SIZE+1)
		{
			if(cmd_code >= 1 && cmd_code <= 63) //Port Readings
			{
				if(erxcount == MAGIC_SIZE+1)
				{
					cmd_port=c;
					erxcount++;
					erxtimeout=0;
					return;
				}
					
				if(erxcount == MAGIC_SIZE+2)
				{
					erxaddrcount=c;
					if(erxaddrcount == 0 || erxaddrcount > MAX_ADDR_COUNT)
					{
						send_error_reply_only(ERROR_BADADDRCOUNT, 0);
						erxcount=0;
					}
					else
					{
						erxcount++;
					}
				}
				else if(erxcount >= MAGIC_SIZE+3 && ((erxcount-(MAGIC_SIZE+3))%2) == 0)
				{
					cmd_addrs[(erxcount-(MAGIC_SIZE+3))/2] = c;
					erxcount++;
				}
				else if(erxcount >= MAGIC_SIZE+3 && ((erxcount-(MAGIC_SIZE+3))%2) == 1)
				{
					cmd_addrs[(erxcount-(MAGIC_SIZE+3))/2] +=c <<8;
					erxcount++;
				}

				if(erxcount >= erxaddrcount*2+MAGIC_SIZE+3)
				{	
					activate=true;
					erxcount=0;
				}
				erxtimeout=0;
			}
			else if(cmd_code == CC_PING || cmd_code == CC_HUBVERSION) //PING
			{
				if(erxcount == MAGIC_SIZE+1)
				{
					cmd_addrs[0]=c;
					erxcount++;
				}
				else if(erxcount == MAGIC_SIZE+2)
				{
					cmd_addrs[0] += c << 8;
					activate = true;
					erxcount = 0;
				}
				erxtimeout=0;
			}
		}
		else if((cmd_code == CC_GUNITREAD || cmd_code == CC_CALREAD || cmd_code == CC_CALSET) && erxcount == MAGIC_SIZE+1)
		{
			cmd_codep=c;
			erxcount++;
			erxtimeout=0;
			return;
		}
		else if((cmd_code == CC_GUNITREAD || cmd_code == CC_CALREAD || cmd_code == CC_CALSET) && erxcount == MAGIC_SIZE+2)
		{
			cmd_size=c;
			erxtimeout=0;
			if(cmd_size > USIZE_MAX) {
				erxcount=0;
			} else {
				erxcount++;
			}
			return;
		}
		else if(cmd_code == CC_CALSET)
		{
			if(erxcount == MAGIC_SIZE+3)
			{
				cmd_port=c;
				cmd_cal_setcount=0;
			} else if (erxcount == MAGIC_SIZE+4) {
				erxaddrcount=1;
				cmd_addrs[0] = c;
			} else if (erxcount == MAGIC_SIZE+5) {
				cmd_addrs[0] +=c <<8;
			} else if (erxcount > MAGIC_SIZE+5) {
				//get until cmd_size amount then done
				cmd_cal_set[cmd_cal_setcount]=c;
				cmd_cal_setcount++;
				if(cmd_cal_setcount == cmd_size) {
					activate=true;
					erxcount=0;
					return;
				}
			}
			erxcount++;
			erxtimeout=0;
		}
		else if((cmd_code == CC_GUNITREAD || cmd_code == CC_CALREAD) && erxcount >= MAGIC_SIZE+3)
		{
			if(cmd_codep >= 1 && cmd_codep <= 63) //Port Readings
			{
				if(erxcount == MAGIC_SIZE+3)
				{
					cmd_port=c;
					erxcount++;
					erxtimeout=0;
					return;
				}
					
				if(erxcount == MAGIC_SIZE+4)
				{
					erxaddrcount=c;
					if(erxaddrcount == 0 || erxaddrcount > MAX_ADDR_COUNT)
					{
						send_error_reply_only(ERROR_BADADDRCOUNT, 0);
						erxcount=0;
					}
					else
					{
						erxcount++;
					}
				}
				else if(erxcount >= MAGIC_SIZE+5 && ((erxcount-(MAGIC_SIZE+5))%2) == 0)
				{
					cmd_addrs[(erxcount-(MAGIC_SIZE+5))/2] = c;
					erxcount++;
				}
				else if(erxcount >= MAGIC_SIZE+5 && ((erxcount-(MAGIC_SIZE+5))%2) == 1)
				{
					cmd_addrs[(erxcount-(MAGIC_SIZE+5))/2] +=c <<8;
					erxcount++;
				}

				if(erxcount >= erxaddrcount*2+MAGIC_SIZE+5)
				{	
					activate=true;
					erxcount=0;
				}
				erxtimeout=0;
			}
		}
	}
}

//Recieves input from UNIT
void unit_input(uint8_t c, uint16_t addr)
{
	if(!urxdone)
	{
		if(urxidx < 4 && check_magic(c, urxidx))
		{
			urxidx++;
			return;
		}
		else if(urxidx < 4 && urxidx != 0)
		{
			urxidx = 0;
			unit_input(c, addr);
		}
		if(urxidx >= 4 )
		{
			if(urxidx == 4)
			{
				urxbuffer[0]=MAGIC0;
				urxbuffer[1]=MAGIC1;
				urxbuffer[2]=MAGIC2;
				urxbuffer[3]=MAGIC3;
			}

			urxbuffer[urxidx]=c;
			urxidx++;
			if(urxidx == 8) {
				if(urxbuffer[7] > USIZE_MAX) {
					urxidx=0;
					urxdone=true;
				}
			}
			if(urxidx > 8 && urxidx == 9+urxbuffer[7])
			{
				//Check if correct address, if not keep listening from the beginning
				if( ((uint16_t)(urxbuffer[5]) << 8) + urxbuffer[4] == addr)
				{
					urxdone=true;
					urxidx=0;
				}
				else
				{
					urxidx=0;
				}
			}
		}
	}
}


void ioinit(void)
{
	softuart_init();
	softuart_turn_rx_on();
	//Turn on watch dog
	wdt_enable(WDTO_8S);
	sei(); //Enable interrupts
	DDRD &=~_BV(PD0); //Read on hw rx usart 
	DDRD |= _BV(PD1);

	//Hardware USART
	UBRR0H = UBRRH_VALUE;
	UBRR0L = UBRRL_VALUE;
	//UCSR0B = (1<<RXEN0)|(1<<TXEN0)|(1<<RXCIE0);
	UCSR0B = (1<<RXEN0)|(1<<TXEN0);
	stdout = &mystdout;
	stderr = &suart_stream;
	//Init RS485 RE DE ports
	//Output on RE and DE pins
	RSP1REDDR |= _BV(RSP1RE);
	RSP1DEDDR |= _BV(RSP1DE);
	RSP2REDDR |= _BV(RSP2RE);
	RSP2DEDDR |= _BV(RSP2DE);
	RSP3REDDR |= _BV(RSP3RE);
	RSP3DEDDR |= _BV(RSP3DE);
	RSP4REDDR |= _BV(RSP4RE);
	RSP4DEDDR |= _BV(RSP4DE);
	RSP5REDDR |= _BV(RSP5RE);
	RSP5DEDDR |= _BV(RSP5DE);
	RSP6REDDR |= _BV(RSP6RE);
	RSP6DEDDR |= _BV(RSP6DE);
	disable_rsports();
}


//Simple memcpy implementation
void* mymemcpy(void *dest, const void *src, size_t count)
{
	char *d = (char*) dest;
	char *s = (char*) src;
	while(count--)
	{
		*d++=*s++;
	}
	return dest;
}



/*
 * Send character to serial
 */
static int uart_putchar(char c, FILE *stream)
{
	//if (c == '\n') uart_putchar('\r', stream);

	loop_until_bit_is_set(UCSR0A, UDRE0);
	UDR0 = c;

	return 0;
}

// interface between avr-libc stdio and the modified Fleury uart-lib:
static int swuart_putchar( char c, FILE *stream )
{
	//if ( c == '\n' ) {
	//softuart_putchar( '\r' );
	//}
	softuart_putchar( c );

	return 0;
}

void uart_rxflush(void)
{
	while(uart_kbhit())
	{
		uart_getchar();
	}
}

/**
 * Is there a character in buffer?
 */
uint8_t uart_kbhit(void)
{
	return (UCSR0A & (1<<RXC0));
}


/*
 * Get character from serial
 */
uint8_t uart_getchar(void)
{
	while( !(UCSR0A & (1<<RXC0)) );
	return(UDR0);
}

/*
 * Keeps track if magic bytes were sent
 * return true if we recieved all magic bytes.
 */
bool check_magic(uint8_t c, uint8_t idx)
{
	//Change if you change MAGIC_SIZE
	if((idx == 0 && c != MAGIC0) || (idx == 1 && c != MAGIC1) || 
			(idx == 2 && c != MAGIC2) || (idx == 3 && c != MAGIC3) )
	{
		return false;
	}
	return true;
}



/*
 * Disable RE and DE on all RS485 chips.
 */
void disable_rsports(void)
{
	//High is Disabled for RE
	RSP1REPORT |= _BV(RSP1RE);
	RSP1DEPORT &= ~_BV(RSP1DE);

	RSP2REPORT |= _BV(RSP2RE);
	RSP2DEPORT &= ~_BV(RSP2DE);

	RSP3REPORT |= _BV(RSP3RE);
	RSP3DEPORT &= ~_BV(RSP3DE);

	RSP4REPORT |= _BV(RSP4RE);
	RSP4DEPORT &= ~_BV(RSP4DE);

	RSP5REPORT |= _BV(RSP5RE);
	RSP5DEPORT &= ~_BV(RSP5DE);

	RSP6REPORT |= _BV(RSP6RE);
	RSP6DEPORT &= ~_BV(RSP6DE);

}

/*
 * Enable RE and DE for just port.
 */
void enable_rsport(uint8_t port)
{
	disable_rsports();

#ifdef DEBUG
	printf("DEBUG: enable_rsport %d\r\n", port);
#endif

	//Low is enable for RE
	//High is enable for DE
	if(port == 1)
	{
		RSP1REPORT &= ~_BV(RSP1RE);
		RSP1DEPORT |= _BV(RSP1DE);
	}
	else if(port == 2)
	{
		RSP2REPORT &= ~_BV(RSP2RE);
		RSP2DEPORT |= _BV(RSP2DE);
	}
	else if(port == 3)
	{
		RSP3REPORT &= ~_BV(RSP3RE);
		RSP3DEPORT |= _BV(RSP3DE);
	}
	else if(port == 4)
	{
		RSP4REPORT &= ~_BV(RSP4RE);
		RSP4DEPORT |= _BV(RSP4DE);
	}
	else if(port == 5)
	{
		RSP5REPORT &= ~_BV(RSP5RE);
		RSP5DEPORT |= _BV(RSP5DE);
	}
	else if(port == 6)
	{
		RSP6REPORT &= ~_BV(RSP6RE);
		RSP6DEPORT |= _BV(RSP6DE);
	}
}

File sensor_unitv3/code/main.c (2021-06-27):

//   Copyright 2010-2019 Dan Elliott, Russell Valentine
//
//   Licensed under the Apache License, Version 2.0 (the "License");
//   you may not use this file except in compliance with the License.
//   You may obtain a copy of the License at
//
//       http://www.apache.org/licenses/LICENSE-2.0
//
//   Unless required by applicable law or agreed to in writing, software
//   distributed under the License is distributed on an "AS IS" BASIS,
//   WITHOUT WARRANTIES OR CONDITIONS OF ANY KIND, either express or implied.
//   See the License for the specific language governing permissions and
//   limitations under the License.
//UNITADDR and UNITFEATURES needs to be defined for each unit on compile/load
#define BAUD 9600

#include <stdbool.h>
#include <stdio.h>
#include <avr/io.h>
#include <avr/interrupt.h>
#include <avr/wdt.h>
#include <avr/eeprom.h>
#include <util/delay.h>
#include <util/setbaud.h>
#include <util/crc16.h>

#ifdef MODULE_TH
#include "./modules/sht75.h"
#endif

#if defined(MODULE_PRESSUREV4A) || defined(MODULE_PRESSUREV4B) || defined(MODULE_MULTITEMP)
#include "i2cmaster/i2cmaster.h"
#endif

#if defined(MODULE_ANEMOMETER) || defined(MODULE_PRESSUREV1) || defined(MODULE_PRESSUREV5)
#include "adc.h"
#endif

#if defined(MODULE_ANEMOMETER)
#include "anemometer/anemometer.h"
#endif

#if defined(MODULE_ANEMOMETERV2)
#include "anemometerv2/anemometer.h"
#endif

#if defined(MODULE_PRESSUREV1)
#include "pressurev1/pressurev1.h"
#endif

#if defined(MODULE_PRESSUREV5)
#include "pressurev5/pressurev5.h"
#endif

#ifdef MODULE_MULTITEMP
#include "multitemp/multitemp.h"
#endif

#ifdef MODULE_PRESSUREV4A
#include "pressurev4a/pressure.h"
#endif

#ifdef MODULE_PRESSUREV4B
#include "pressurev4b/pressure.h"
#endif

#ifdef MODULE_TACHOMETER
#include "./modules/tachometer.h"
#endif

#ifdef MODULE_THERMOCOUPLE
#include "./modules/thermocouplev2/thermocouple.h"
#endif

//#define DEBUG

#ifdef DEBUG
#include "softuart.h"
#endif

#define MAGIC0 'D'
#define MAGIC1 'E'
#define MAGIC2 'R'
#define MAGIC3 'V'
#define MAGIC_SIZE 4
#define MAX_TXBUF_LEN 17 //MAGIC_SIZE + Addr(2)+cc(1)+s(1)+max_s_value(8)+crc(1)

#define RS485RE PB0
#define RS485REPORT PORTB
#define RS485REDDR DDRB
#define RS485DE PD4
#define RS485DEPORT PORTD
#define RS485DEDDR DDRD

//Command codes
#define CC_TEMP_HUM 1
#define CC_ANEMOMETER 2
#define CC_TACHOMETER 3
#define CC_THERMOCOUPLE 6
#define CC_PRESSURE 7
#define CC_PRESSURE_WIDE 8
#define CC_PRESSURE_WIDE_CALSIZE 4
#define CC_PRESSURE_DIFF_WIDE 14
#define CC_MULTITEMP_RESET 9
#define CC_MULTITEMP_CH1 10
#define CC_MULTITEMP_CH2 11
#define CC_MULTITEMP_CH3 12
#define CC_MULTITEMP_CH4 13
#define CC_MULTITEMP_ADDR_CH1 14
#define CC_MULTITEMP_ADDR_CH2 15
#define CC_MULTITEMP_ADDR_CH3 16
#define CC_MULTITEMP_ADDR_CH4 17
//#define CC_MULTITEMP
#define CC_UNIT_VERSION 63
#define CC_CAL_GET 64
#define CC_CAL_SET 65
#define CC_CHANGE_ADDRESS 200

#define ADAVG_COUNT 5
#define ADAVG_DELAYMS 50 

#define UNIT_VERSION 3


static void ioinit(void);
static int uart_putchar(char c, FILE *stream);
uint8_t uart_kbhit(void);
static uint8_t uart_getchar(void);
static uint8_t calsize(uint8_t findcc);
void hub_input(uint8_t c);
static bool check_magic(uint8_t c);
static void *mymemcpy(void *dest, const void *src, size_t count);

#ifdef DEBUG
static int swuart_putchar( char c, FILE *stream );
#endif

static FILE mystdout = FDEV_SETUP_STREAM(uart_putchar, NULL, _FDEV_SETUP_WRITE);
#ifdef DEBUG
static FILE suart_stream = FDEV_SETUP_STREAM(swuart_putchar, NULL, _FDEV_SETUP_WRITE );
#endif
static uint8_t rxcount=0;
static uint16_t rxaddr=0;
static uint16_t chaddr=0;
static uint8_t cc=0;
static uint8_t cal_cc=0;
static uint8_t cal_val[8];
uint16_t EEMEM ee_addr=UNITADDR;
static uint16_t myaddr=0;
static uint8_t volatile activate=0;
static unsigned char txbuffer[MAX_TXBUF_LEN];

int main(void)
{
	uint8_t crc = 0, i=0, ch = 0;
	uint8_t s = 0;
	uint16_t t=0, h=0;
	uint32_t t2=0;
	uint32_t pres=0;
	int32_t it2=0;
	uint8_t t8[8];
	double convert=0.0,convert2=0.0;
	myaddr = eeprom_read_word(&ee_addr);
	ioinit();
	//TXBUFFER=Magic(4b),Address(2b),CC(1b),S(1b),Data(Sb),CRC8(1b)
	txbuffer[0]=MAGIC0;
	txbuffer[1]=MAGIC1;
	txbuffer[2]=MAGIC2;
	txbuffer[3]=MAGIC3;
	mymemcpy(&txbuffer[MAGIC_SIZE], &myaddr, 2);
#ifdef DEBUG
			fprintf(stderr, "D: Unit addr=%d.\r\n", myaddr);
#endif
	while(1)
	{
		if(activate)
		{
#ifdef DEBUG
			//fprintf(stderr, "D: go\r\n");
#endif
			activate = 0;
			txbuffer[MAGIC_SIZE+2]=cc;
			if(cc == CC_UNIT_VERSION) {
				s = 2;
				txbuffer[MAGIC_SIZE+3]=s;
				t = UNIT_VERSION;
				mymemcpy(&txbuffer[MAGIC_SIZE+4], &t, 2);
			}
#ifdef MODULE_TH
			else if(cc == CC_TEMP_HUM)
			{
				s = 4;
				txbuffer[MAGIC_SIZE+3]=s; //S
				t = sht_read_raw_temperature();
				h = sht_read_raw_humidity();
				mymemcpy(&txbuffer[MAGIC_SIZE+4], &t, 2);
				mymemcpy(&txbuffer[MAGIC_SIZE+6], &h, 2);
			} 
#endif
#if defined(MODULE_ANEMOMETER) || defined(MODULE_ANEMOMETERV2)
			else if (cc == CC_ANEMOMETER)
			{
				s=2;
				txbuffer[MAGIC_SIZE+3]=s; //S
				//Get wind speed reading.
				t=anemometer_mph();
				mymemcpy(&txbuffer[MAGIC_SIZE+4], &t, 2);
			}
#endif
#ifdef MODULE_PRESSUREV4A
			else if (cc == CC_PRESSURE)
			{
				s=2;
				txbuffer[MAGIC_SIZE+3]=s; //S
				//Get pressure.
				t=pressure_get();
				mymemcpy(&txbuffer[MAGIC_SIZE+4], &t, 2);
			}
			else if (cc == CC_PRESSURE_WIDE)
			{
				s=4;
				txbuffer[MAGIC_SIZE+3]=s; //S
				//Get full pressure.
				t2=pressure_get_full();
				mymemcpy(&txbuffer[MAGIC_SIZE+4], &t2, 4);
			}
#endif
#ifdef MODULE_PRESSUREV4B
			else if(cc == CC_TEMP_HUM)
			{
				s = 4;
				txbuffer[MAGIC_SIZE+3]=s; //S
				pressure_temp_rh_get_full(&pres, &it2, &t2);
				t = t_to_shtt(it2);
				h = (uint16_t)(t2);
				mymemcpy(&txbuffer[MAGIC_SIZE+4], &t, 2);
				mymemcpy(&txbuffer[MAGIC_SIZE+6], &h, 2);
			} 
			else if (cc == CC_PRESSURE)
			{
				s=2;
				txbuffer[MAGIC_SIZE+3]=s; //S
				//Get pressure.
				t=pressure_get();
				mymemcpy(&txbuffer[MAGIC_SIZE+4], &t, 2);
			}
			else if (cc == CC_PRESSURE_WIDE)
			{
				s=4;
				txbuffer[MAGIC_SIZE+3]=s; //S
				//Get full pressure.
				t2=pressure_get_full();
				mymemcpy(&txbuffer[MAGIC_SIZE+4], &t2, 4);
			}
#endif
#ifdef MODULE_PRESSUREV1
			else if (cc == CC_PRESSURE)
			{
				s=2;
				txbuffer[MAGIC_SIZE+3]=s; //S
				t=pressurev1_get();
				mymemcpy(&txbuffer[MAGIC_SIZE+4], &t, 2);
			}
			else if (cc == CC_PRESSURE_WIDE)
			{
				s=4;
				txbuffer[MAGIC_SIZE+3]=s; //S
				t2=pressurev1_get_wide();
				mymemcpy(&txbuffer[MAGIC_SIZE+4], &t2, 4);
			}
#endif
#ifdef MODULE_PRESSUREV5
			else if (cc == CC_PRESSURE_DIFF_WIDE)
			{
				s=4;
				txbuffer[MAGIC_SIZE+3]=s; //S
				t2=pressurev5_get_wide();
				mymemcpy(&txbuffer[MAGIC_SIZE+4], &t2, 4);
			}
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

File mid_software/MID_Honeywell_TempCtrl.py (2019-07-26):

#   Copyright 2010-2019 Dan Elliott, Russell Valentine
#
#   Licensed under the Apache License, Version 2.0 (the "License");
#   you may not use this file except in compliance with the License.
#   You may obtain a copy of the License at
#
#       http://www.apache.org/licenses/LICENSE-2.0
#
#   Unless required by applicable law or agreed to in writing, software
#   distributed under the License is distributed on an "AS IS" BASIS,
#   WITHOUT WARRANTIES OR CONDITIONS OF ANY KIND, either express or implied.
#   See the License for the specific language governing permissions and
#   limitations under the License.
# EA modules
import WWWcomm
import EthModbusComm
# 3rd party modules
import restkit
from daemon import Daemon
import pytz
# std lib modules
import logging
import ConfigParser
import cPickle
import time
import os
import sys
import datetime
import traceback
import gzip

CONFIG_LOC = '../MID.cfg'
LAST_WWW_CONFIG_LOC = 'MID_WWW_Honeywell_TempCtrl'
DATA_BACKUP_LOC = "DATA_BAK"
LOG_LOC = "Honeywell_temp_ctrl.log"

UDC_3300_ID = 12

SP_ID = 21
PV_ID = 20

class MyDaemon(Daemon):
	def run(self):
		try:
			lastWWWcfgDateTime = None
			lastReadingDateTime = None
			lastUploadDateTime = None
			errorState = False
			log_level = logging.INFO

			# load configuration
			config = ConfigParser.ConfigParser()
			config.read(CONFIG_LOC)

			# setup logging
			if config.get("MID","log_level") == "DEBUG":
				log_level = logging.DEBUG
			if config.get("MID","log_level") == "INFO":
				log_level = logging.INFO
			elif config.get("MID","log_level") == "WARNING":
				log_level = logging.WARNING
			elif config.get("MID","log_level") == "ERROR":
				log_level = logging.ERROR
			logging.basicConfig(filename=LOG_LOC, level=log_level, format='%(asctime)s %(message)s')

			# read last WWW configuration saved to disk
			try:
				WWWcfg = readLatestWWWcfg()
			except:
				logging.warning("No WWW config found at " + LAST_WWW_CONFIG_LOC + ".")

			# establish WWW connection
			logging.info("establishing WWW conn")
			MIDname = config.get("HONEYWELL_TEMP_CTRL","MIDname")
			WWWcon = WWWcomm.WWWcomm(config.get("MID","MIDpassword"),
									 config.get("MID","configpath"),
									 config.get("MID","baseurl"),
									 config.get("MID","uploadpath"),
									 config.get("MID","RCstatusPath"),
									 MIDname)
			# get Eth subnet
			ethSubnet = config.get("HONEYWELL_TEMP_CTRL","eth_subnet")

			# 
			# THE MAIN LOOP
			# 
			while(True):
				readingStartTime = datetime.datetime.now()
				# 
				# reload local configuration
				# 
				config.read(CONFIG_LOC)
				# 
				# check shut-off flag
				# 
				if not config.getboolean("MID","turn_off"):
					# 
					# update config from WWW
					# 
					try:
						newWWWcfg = WWWcon.getConfig()
						if newWWWcfg: # if website config updates occured
							WWWcfg = newWWWcfg; logging.debug(str(WWWcfg));
							logging.info("WWW cfg file received.")
							lastWWWcfgDateTime = time.time()
							# 
							# write new cfg to file
							# 
							try:
								writeLatestWWWcfg(WWWcfg)
								logging.info("Wrote WWW cfg to local file")
							except:
								logging.error("Could not write latest WWW configuration to " + LAST_WWW_CONFIG_LOC + ".")
					except:
						logging.error("WWW configuration not received from web server.")
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

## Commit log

2020-08-10 Sensor unit bme 5.10. A cheaper T/RH/P sensor unit backward compatible
    [sensor_unit_bme280.kicad_pcb, sensor_unit_bme280.sch]
2020-08-11 Updated assembly bom, and pictures.
    [sensor_unit_bme280v5.10_BOM.xlsx]
2021-06-27 Supports using PB5(SCK) as anemometer pin with software debounce as alternative to module.

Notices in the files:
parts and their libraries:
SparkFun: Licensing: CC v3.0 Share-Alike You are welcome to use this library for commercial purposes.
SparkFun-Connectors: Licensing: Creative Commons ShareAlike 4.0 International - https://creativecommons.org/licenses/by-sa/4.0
